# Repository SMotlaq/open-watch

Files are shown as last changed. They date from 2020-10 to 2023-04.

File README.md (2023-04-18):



<!-- PROJECT SHIELDS -->
[][contributors-url]
[][forks-url]
[][stars-url]
[][issues-url]
[][license-url]

<!-- TABLE OF CONTENTS -->
<details>
  <summary>Table of Contents</summary>
  <ol>
    <li><a href="#about-the-project">About The Project</a></li>
    <li><a href="#donation">Donation</a></li>
    <li><a href="#components">Components</a></li>
    <li><a href="#roadmap">Roadmap</a></li>
    <li><a href="#pictures">Pictures</a></li>
    <li><a href="#results">Results</a></li>
    <li><a href="#license">License</a></li>
    <li><a href="#refereces">Refereces</a></li>
    <li><a href="#contact">Contact</a></li>
  </ol>
</details>

<!-- ABOUT THE PROJECT -->
# About The Project

### Welcome to Open-Watch ✋🏻😃 a wearable device for health monitoring and fitness tracking.

**Special thanks to [PCBWay](https://www.pcbway.com/) for sponsoring us on this open-source project and providing [these](#pictures) awesome 4-layer PCBs!** Open-Watch is an open-source smartwatch project developed for our B.Sc. final thesis. This smartwatch can measure the linear acceleration of your hand, rotational speed, heart rate, and SpO2 (oxygen saturation). All of these data will be processed by an STM32 processor with an ARM Cortex-M core. You can find these essential components [here](#components).

MPU6050 was used for IMU purposes. We use the Kalman filter to reduce the noise effect and extract clean data from the sensor (3-axis linear acceleration, 3-axis rotational velocity, and 3-axis rotation angle).

MAX30102 is the sensor used for health care purposes. We just read raw data and devolve the processes to the smartphone.

Open-watch will send these collected data to a smartphone via a Bluetooth module. On the smartphone side, an Android app reads the data from Bluetooth and processes them. For health care applications like heart rate and SpO2 analysis, we use ML-based algorithms to extract these parameters from raw data read from the pulse-oximeter sensor. In this section a real-time algorithm for analysis of photoplethysmography signal (PPG) for measurement of SpO2 will be implemented.

The final valuable data will be shown on a smartphone as well as the smartwatch screen.

<div align="center">
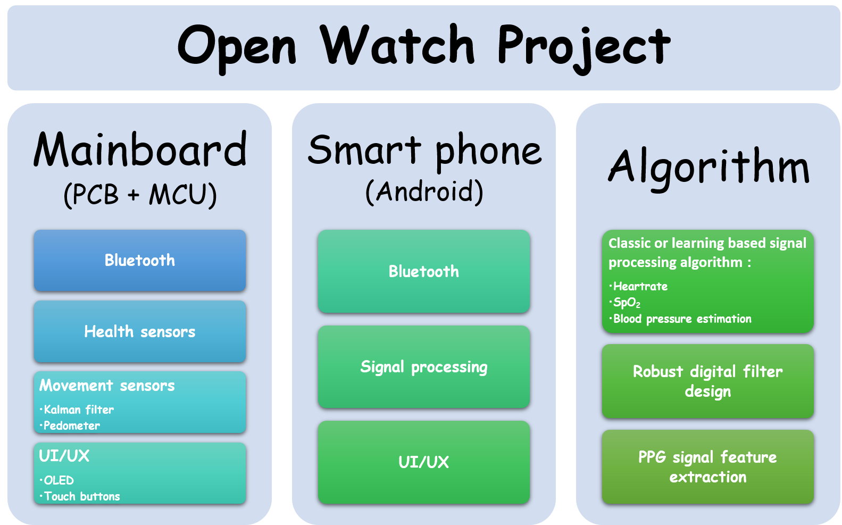
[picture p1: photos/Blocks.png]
    
</div>
<p align="right">(<a href="#top">back to top</a>)</p>

<!-- DONATION -->
# Donation

Do you want to support us in this project?

<p align="left">
  <a href="http://smotlaq.ir/LQgQF">
  Buy me a Coffee
  </a>
</p>

<p align="right">(<a href="#top">back to top</a>)</p>

# Components
 * 4-layer PCB: The PCBs of this project are provided by [PCBWay](https://www.pcbway.com), one of the best PCB factories in the world.
 * Main proccessor: [STM32F030C8 (ARM Cortex-M0)](https://www.javanelec.com/Shops/ProductDetail/24347)
 * Heartbeat and pulse oximeter sensor: [MAX30102](https://www.aliexpress.com/item/1005001863759524.html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)
 * Motion sensor: [MPU6050](http://skytech.ir/product_details.aspx?ID_Parts=2830&MPU6050)
 * Display: [1.3" OLED 64*128 pixels](http://skytech.ir/product_details.aspx?ID_Parts=2006&1.3-inch-I2C-OLED-SSD1306-Module)
 * Vibration [motor](https://www.javanelec.com/Shops/ProductDetail/38512)
 * Bluetooth: [HC-05](https://www.javanelec.com/Shops/ProductDetail/30407)
 * Touch driver: [BS814-A](https://micromodern.ir/shop/touch-key-ic/bs814a-1-msop10/)
 * Battery: [3.7v Li-Po](https://micmodshop.ir/eshop/battery-products/batteries/battery-lithium-polymer-3-7v-400mah-custom-00/)
 * Battery charger: [TP4056](http://skytech.ir/product_details.aspx?ID_Parts=9929&TP4056%20SOP8)

<p align="right">(<a href="#top">back to top</a>)</p>

<!-- ROADMAP -->
# Roadmap

- [x] Hardware design
  - [x] Microcontroller
  - [x] Vibration motor
  - [x] Bluetooth
  - [x] Buzzer
  - [x] Touch keys
  - [x] Charger
  - [X] PPG sensor
  - [X] MPU6050
- [X] PCB design
- [X] PCB Ordering
- [X] Body design
- [X] 3D print
- [x] Soldeing
- [x] Firmware programming
  - [x] RTC
  - [x] Alarm
  - [x] Bluetooth commands
  - [x] Vibration waves
  - [x] Buzzer
  - [x] OLED
    - [x] UI/UX
  - [x] Touch buttons
  - [x] Battery level indicator
  - [x] MPU6050
    - [x] Get raw data
    - [x] Kalman filter
    - [x] Movement detection
  - [x] PPG sensor
    - [x] Get raw data
    - [x] Transfer data using Bluetooth
- [x] Android programming
  - [x] Get blutooth data
  - [x] UI/UX
  - [x] Plot the raw PPG signals
  - [x] PPG data analysis
    - [x] Heartbeat
    - [x] SpO2
- [x] Assembling
- [x] Final test 😎

See the [open issues](https://github.com/SMotlaq/open-watch/issues) for a full list of proposed features (and known issues).

<p align="right">(<a href="#top">back to top</a>)</p>

<!-- PARTS -->
# Pictures

**OpenWatch**
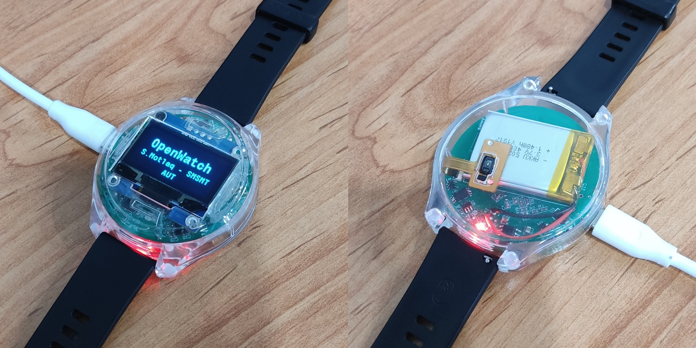
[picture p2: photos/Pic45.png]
 

<!-- ![full](photos/Pic45.png?raw=true "Fully assembled") -->

**PCB Overview**
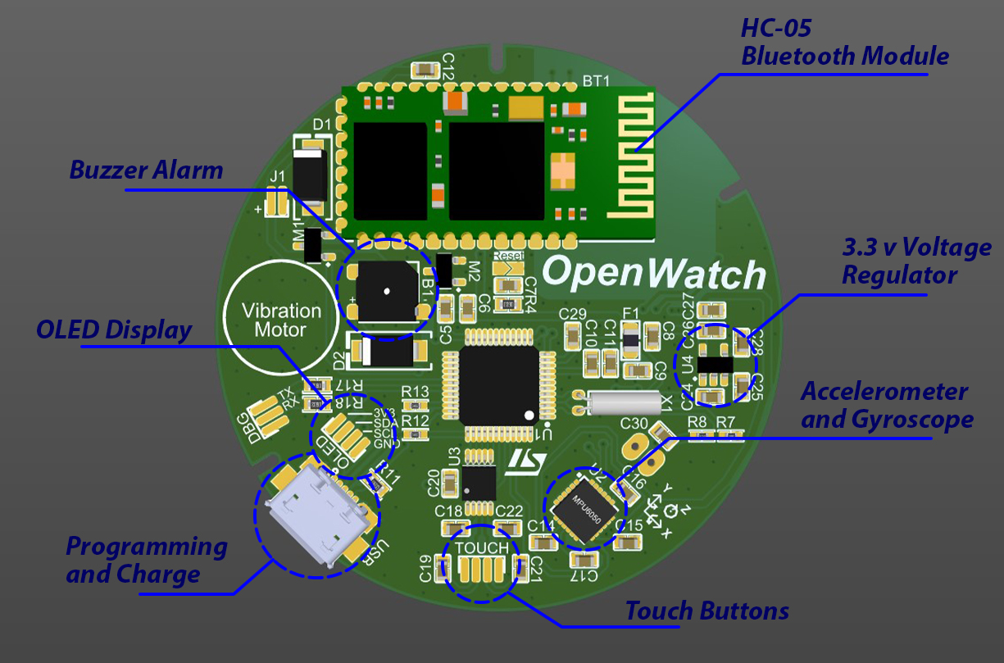
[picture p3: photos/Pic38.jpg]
 
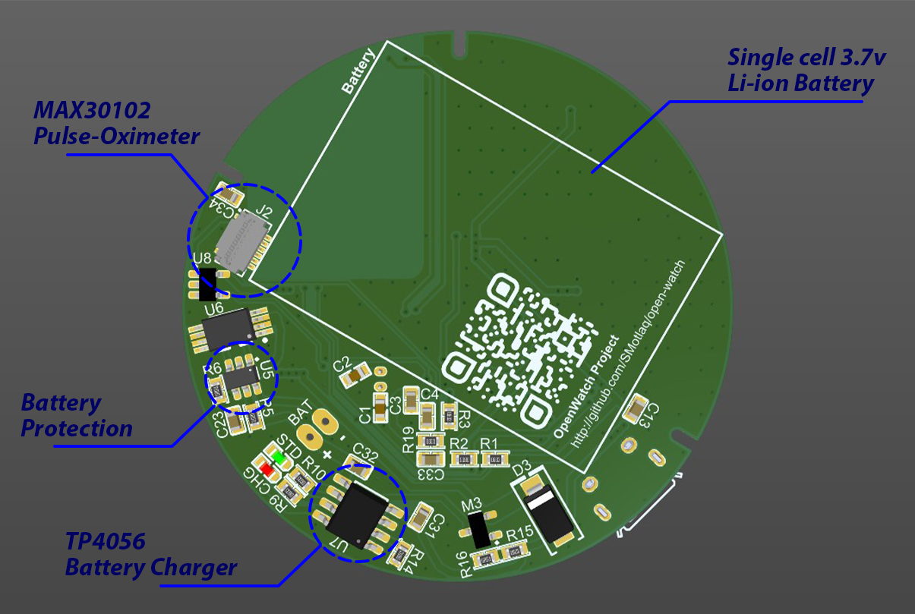
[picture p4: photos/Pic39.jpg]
 

<!-- ![overview-front](photos/Pic38.jpg?raw=true "Overview - Front")
![overview-back](photos/Pic39.jpg?raw=true "Overview - Back") -->

**PCB - 2D** 
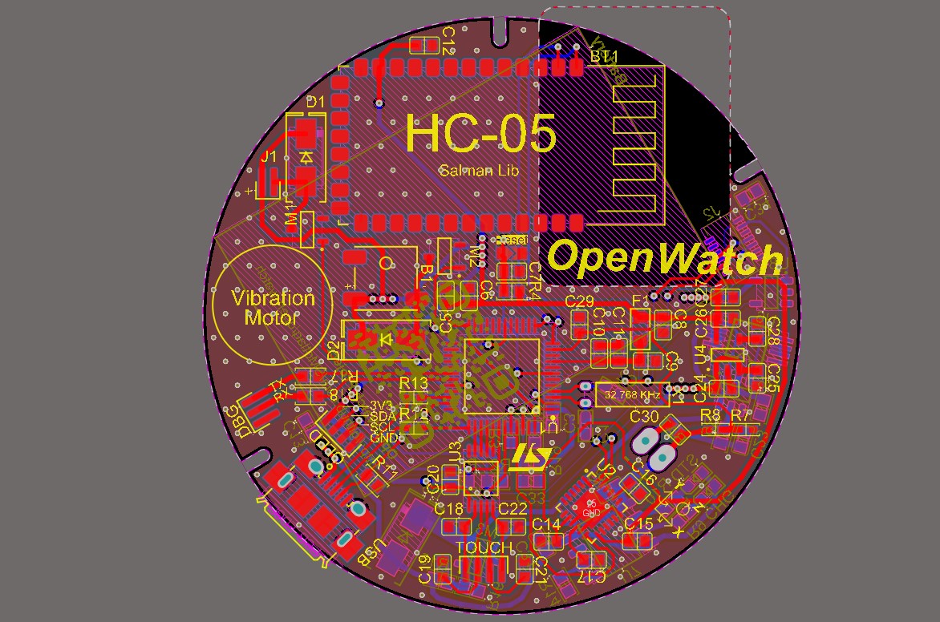
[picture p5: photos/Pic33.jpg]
 

<!-- ![2D](photos/Pic33.jpg?raw=true "2D view of main PCB - both layers") -->

**PCB - 3D** 
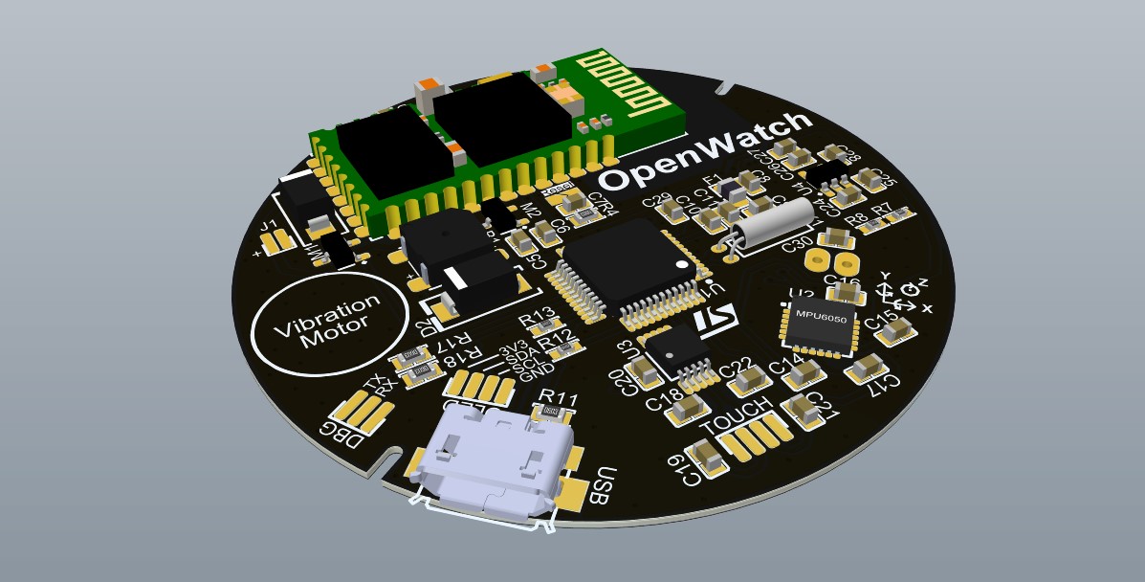
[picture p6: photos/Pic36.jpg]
  
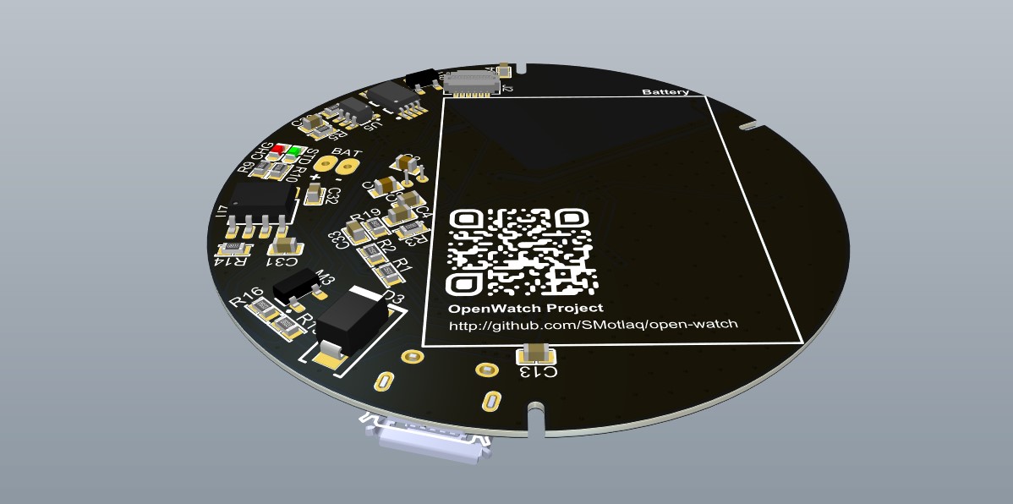
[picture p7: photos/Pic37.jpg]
 

<!-- ![3D-front](photos/Pic36.jpg?raw=true "3D view of main PCB - front")
![3D-back](photos/Pic37.jpg?raw=true "3D view of main PCB - back") -->

**PCB - Real**
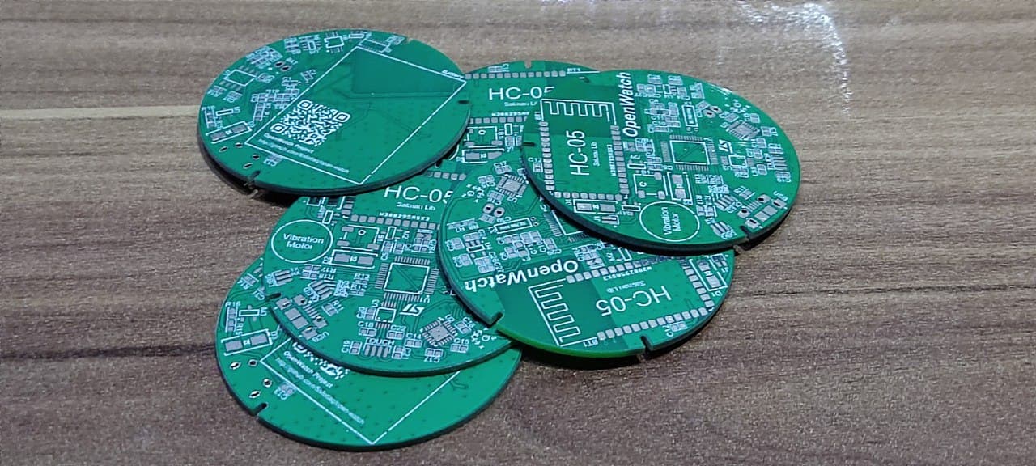
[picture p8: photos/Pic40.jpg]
  
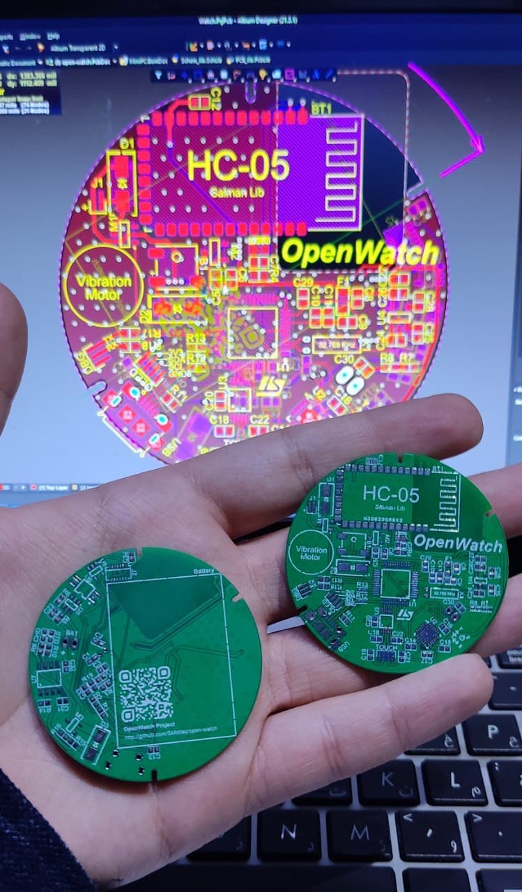
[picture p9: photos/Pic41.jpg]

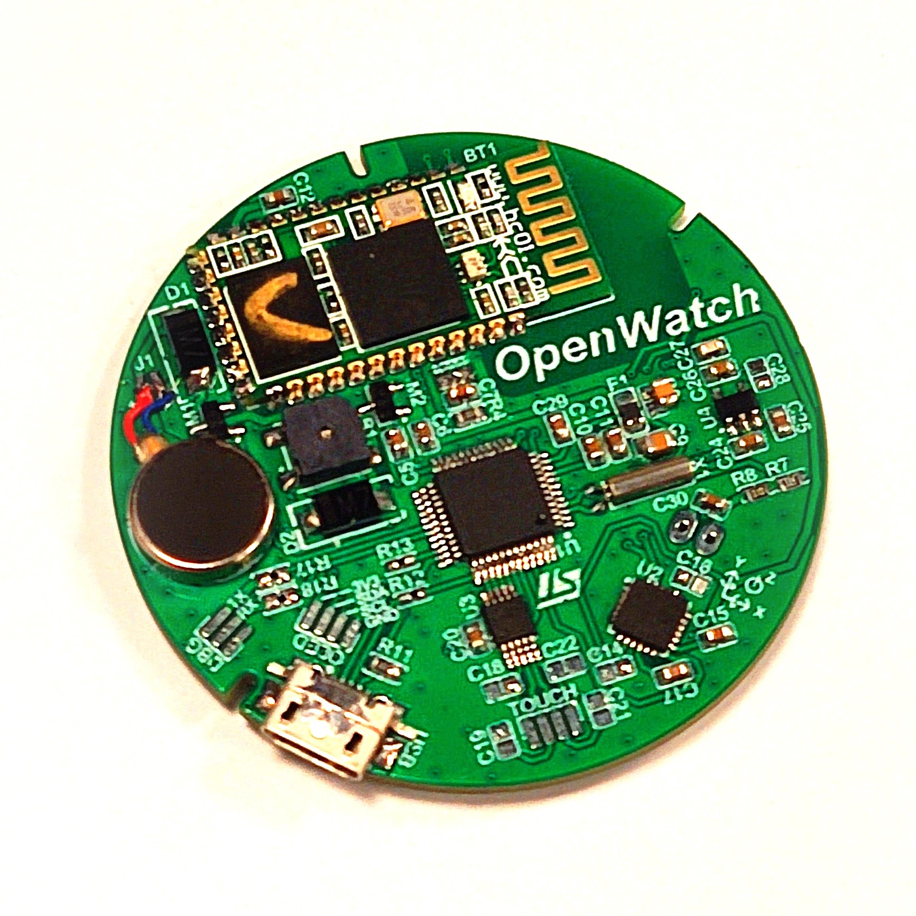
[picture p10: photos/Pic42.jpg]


<!-- ![real-front](photos/Pic32.jpg?raw=true "Real PCB view - front")
![real-back](photos/Pic31.jpg?raw=true "Real PCB view - back") -->

<p align="right">(<a href="#top">back to top</a>)</p>

<!-- STARS -->
# Star history

Star History Chart (https://star-history.com/#SMotlaq/open-watch&Date)

<p align="right">(<a href="#top">back to top</a>)</p>

<!-- LICENSE -->
# License

Distributed under the MIT License. See `LICENSE.txt` for more information.

<p align="right">(<a href="#top">back to top</a>)</p>

<!-- REFERENCES -->
# Refereces
**Dataset:**

MIMIC-III Database (https://mimic.mit.edu)

  [1] *Johnson, A., Pollard, T., & Mark, R. (2016). MIMIC-III Clinical Database (version 1.4). PhysioNet. https://doi.org/10.13026/C2XW26.*
  
  [2]	*Moody, B., Moody, G., Villarroel, M., Clifford, G., & Silva, I. (2020). MIMIC-III Waveform Database (version 1.0). PhysioNet. https://doi.org/10.13026/c2607m*
  
  [3]	*Kemp, J., Zhang, K., & Dai, A. (2020). MIMIC-III - SequenceExamples for TensorFlow modeling (version1.0.0). PhysioNet. https://doi.org/10.13026/n2v5-5b32.*
  
**Main references:**

 [1]	*Kiyasseh et al, CLOCS: Contrastive learning of cardiac signals across space, time, and patients, In Proc. ICML 2021*
 
 [2]	*Torres-Soto, J., Ashley, E.A. Multi-task deep learning for cardiac rhythm detection in wearable devices. npj Digit. Med. 3, 116 (2020). https://doi.org/10.1038/s41746-020-00320-4*
 
 [3]	*El Hajj C, Kyriacou P.A. Cuffless blood pressure estimation from PPG signals and its derivatives using deep learning models, Biomedical Signal Processing and Control. 70 (2021) https://doi.org/10.1016/j.bspc.2021.102984* 
 
 [4]	*Solà, J., & Delgado-Gonzalo, R. (2019). The Handbook of Cuffless Blood Pressure Monitoring: A Practical Guide for Clinicians, Researchers, and Engineers. The Handbook of Cuffless Blood Pressure Monitoring. https://doi.org/10.1007/978-3-030-24701-0*

<p align="right">(<a href="#top">back to top</a>)</p>

<!-- CONTACT -->
# Contact

Salman AmiMotlaq - [@SMotlaq](https://github.com/SMotlaq) - pilot.motlaq@gmail.com

Seyedmohammadsaleh Mirzatabatabaei - [@seyedsaleh](https://github.com/seyedsaleh) - seyedsaleh.edu@gmail.com

Amirhossein Aghajari - [@Aghajari](https://github.com/Aghajari) - amirhossein.aghajari.82@gmail.com

Project Link: [https://github.com/SMotlaq/open-watch](https://github.com/SMotlaq/open-watch)

<p align="right">(<a href="#top">back to top</a>)</p>

<!-- MARKDOWN LINKS & IMAGES -->
<!-- https://www.markdownguide.org/basic-syntax/#reference-style-links -->
[contributors-shield]: https://img.shields.io/github/contributors/SMotlaq/open-watch.svg?style=for-the-badge
[contributors-url]: https://github.com/SMotlaq/open-watch/graphs/contributors
[forks-shield]: https://img.shields.io/github/forks/SMotlaq/open-watch.svg?style=for-the-badge
[forks-url]: https://github.com/SMotlaq/open-watch/network/members
[stars-shield]: https://img.shields.io/github/stars/SMotlaq/open-watch.svg?style=for-the-badge
[stars-url]: https://github.com/SMotlaq/open-watch/stargazers
[issues-shield]: https://img.shields.io/github/issues/SMotlaq/open-watch.svg?style=for-the-badge
[issues-url]: https://github.com/SMotlaq/open-watch/issues
[license-shield]: https://img.shields.io/github/license/SMotlaq/open-watch.svg?style=for-the-badge
[license-url]: https://github.com/SMotlaq/open-watch/blob/master/LICENSE.txt

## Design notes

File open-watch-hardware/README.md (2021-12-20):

# Docs about open-watch hardware

## Things that should be changed in future versions:
 * Connect 8th pin of TP4056 to MCU. It will let us to control battery charging.
 * Swap the Rx & Tx of Bluetooth
 * Connect PIO11 (HC-05) to MCU for changing the name, password, baudrate, etc.
 * Connect USB_DETECT label to +5V of USB instead of ID pin.

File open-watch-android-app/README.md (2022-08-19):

# open-watch android app

**Libraries/Projects Used:**
- [XmlByPass](https://github.com/Aghajari/XmlByPass)
- [AXAnimation](https://github.com/Aghajari/AXAnimation)
- [AXGraphView](https://github.com/Aghajari/AXGraphView)
- [AXPathLoadingView](https://github.com/Aghajari/AXPathLoadingView)
- [SimpleChart](https://github.com/Aghajari/SimpleChart)

## Connection
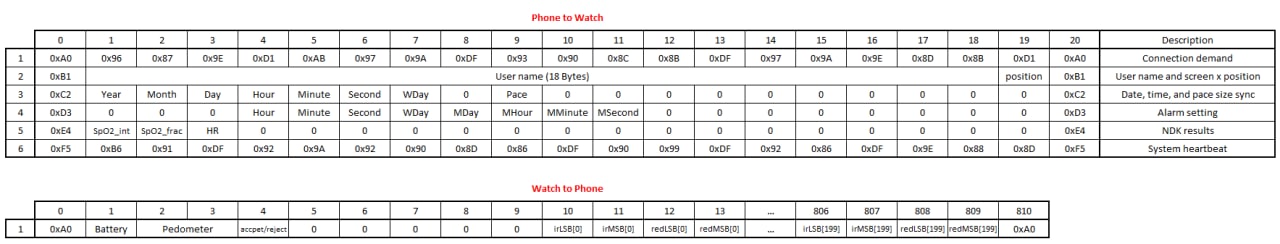
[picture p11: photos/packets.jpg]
Packets


Android app connects to watch via classic bluetooth. <br>
Whenever the socket created, android app sends the `Connection demand` packet and waits for the acknowledge.<br>
Then app sends a filtered username to the watch so watch can say Hello to that user.<br>
At the end app sends some config data to the watch such as user's device date & time and user's step-size to calculate distance in km.<br>
App sends the `System heartbeat` packet to watch every 800ms so that watch verifies the app.<br>
App sends the `Alarm setting` packet whenever the user sets an alarm.<br>
Whenever the watch sends 5 signal packets (1000 samples) to the app, the PPG algorithms will filter the signal and calculate HR and SpO2, and then the app will send the `NDK results` packet to the watch.

## Graph

[AXGraphView](https://github.com/Aghajari/AXGraphView) is customized so that it can increase the range of the time (x) domain by zooming and it is possible to move only in the time axis. Also, scrolling will start automatically upon receiving signals from the watch. The coordinate axis has been moved to (0, 0) and the library is ready to display two different graphs (Red and iRed) in one view.

## HRV Chart

[SimpleChart](https://github.com/Aghajari/SimpleChart)'s LineChart is customized to match the graph's grid-lines design and the gradient animation. Also, the y range is calculated more accurately and a linear animation has been added to display the chart.

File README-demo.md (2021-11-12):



<!-- PROJECT SHIELDS -->
[][contributors-url]
[][forks-url]
[][stars-url]
[][issues-url]
[][license-url]

<!-- PROJECT LOGO -->
<br />
<div align="center">

  <h3 align="center">open-watch</h3>

  <p align="center">
    Smart Wearable Health Monitoring and Fitness Tracking Device
    <br />
    <a href="https://github.com/SMotlaq/open-watch"><strong>Explore the docs »</strong></a>
    <br />
    <br />
    <a href="https://github.com/SMotlaq/open-watch/issues">Report Bug & Request Feature</a>
  </p>
</div>

<!-- TABLE OF CONTENTS -->
<details>
  <summary>Table of Contents</summary>
  <ol>
    <li>
      <a href="#about-the-project">About The Project</a>
      <ul>
        <li><a href="#components">Components</a></li>
      </ul>
    </li>
    <li><a href="#roadmap">Roadmap</a></li>
    <li><a href="#parts">Parts</a></li>
    <li><a href="#results">Results</a></li>
    <li><a href="#license">License</a></li>
    <li><a href="#refereces">Refereces</a></li>
    <li><a href="#contact">Contact</a></li>
    <li><a href="#donation">Donation</a></li>
  </ol>
</details>

<!-- ABOUT THE PROJECT -->
## About The Project

Welcome to Open-Watch ✋🏻😃

Open-Watch is an open source project developed for our BSc final thesis. Wait to hear more from us!
<div align="center">
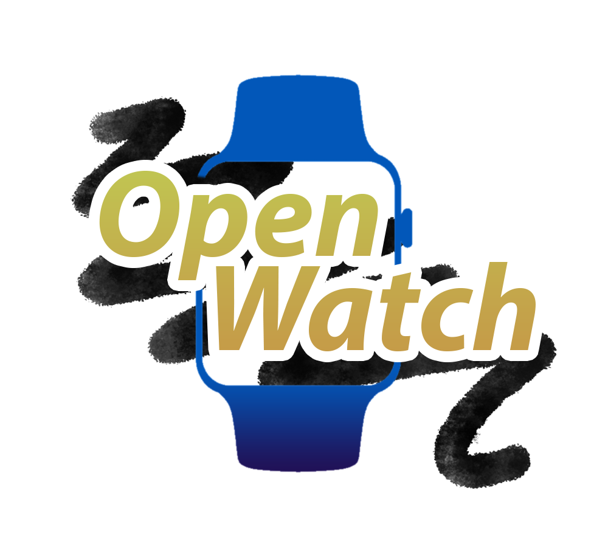
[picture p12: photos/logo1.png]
    
</div>
<p align="right">(<a href="#top">back to top</a>)</p>

### Components
 * Main proccessor: [STM32F030C8 (ARM core)](https://www.javanelec.com/Shops/ProductDetail/24347)
 * Heartbeat and pulse oximeter sensor: [MAX30102](https://www.aliexpress.com/item/1005001863759524.html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)
 * Motion sensor: [MPU6050](http://skytech.ir/product_details.aspx?ID_Parts=2830&MPU6050)
 * Display: [1.3" OLED 64*128 pixels](http://skytech.ir/product_details.aspx?ID_Parts=2006&1.3-inch-I2C-OLED-SSD1306-Module)
 * Vibration [motor](https://www.javanelec.com/Shops/ProductDetail/38512)
 * Bluetooth: [HC-05](https://www.javanelec.com/Shops/ProductDetail/30407)
 * Touch driver: [BS814-A](https://micromodern.ir/shop/touch-key-ic/bs814a-1-msop10/)
 * Battery: [3.7v Li-Po](https://micmodshop.ir/eshop/battery-products/batteries/battery-lithium-polymer-3-7v-400mah-custom-00/)
 * Battery charger: [TP4056](http://skytech.ir/product_details.aspx?ID_Parts=9929&TP4056%20SOP8)

<p align="right">(<a href="#top">back to top</a>)</p>

<!-- ROADMAP -->
## Roadmap

- [x] Hardware design
  - [x] Microcontroller
  - [x] Vibration motor
  - [x] Bluetooth
  - [x] Buzzer
  - [x] Touch keys
  - [x] Charger
  - [X] PPG sensor
  - [X] MPU6050
- [X] PCB design
- [X] PCB Ordering
- [ ] Body design
- [ ] 3D print
- [ ] Soldeing
- [ ] Firmware programming
  - [ ] RTC
  - [ ] Bluetooth commands
  - [ ] Vibration waves
  - [ ] OLED
  - [ ] Touch buttons
  - [ ] Battery level indicator
  - [ ] Power saving
  - [ ] MPU6050
  - [ ] PPG sensor
- [ ] Android programming
- [ ] Assembling
- [ ] Final test 😎

See the [open issues](https://github.com/SMotlaq/open-watch/issues) for a full list of proposed features (and known issues).

<p align="right">(<a href="#top">back to top</a>)</p>

<!-- PARTS -->
## Parts

**Overview**
 
 

<!-- ![overview-front](photos/Pic38.jpg?raw=true "Overview - Front")
![overview-back](photos/Pic39.jpg?raw=true "Overview - Back") -->

**PCB - 2D** 
 

<!-- ![2D](photos/Pic33.jpg?raw=true "2D view of main PCB - both layers") -->

**PCB - 3D** 
  
 

<!-- ![3D-front](photos/Pic36.jpg?raw=true "3D view of main PCB - front")
![3D-back](photos/Pic37.jpg?raw=true "3D view of main PCB - back") -->

**PCB - Real** (***These pictures belong to the previous version***) 
  
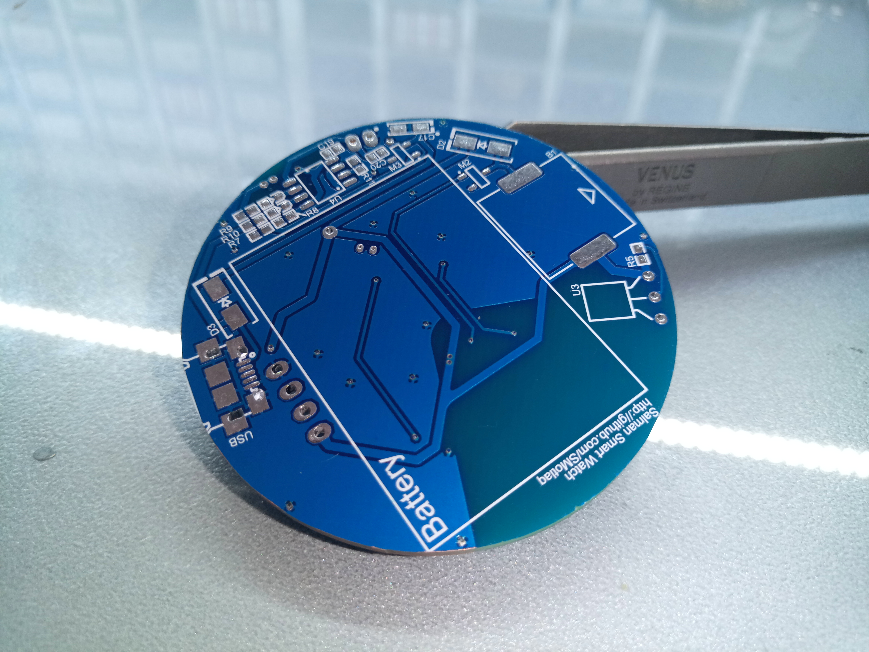
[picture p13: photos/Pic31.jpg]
 

<!-- ![real-front](photos/Pic32.jpg?raw=true "Real PCB view - front")
![real-back](photos/Pic31.jpg?raw=true "Real PCB view - back") -->

<p align="right">(<a href="#top">back to top</a>)</p>

<!-- RESULTS -->
## Results

<p align="right">(<a href="#top">back to top</a>)</p>

<!-- LICENSE -->
## License

Distributed under the MIT License. See `LICENSE.txt` for more information.

<p align="right">(<a href="#top">back to top</a>)</p>

<!-- REFERENCES -->
## Refereces

[1] *blablabla* 

<p align="right">(<a href="#top">back to top</a>)</p>

<!-- CONTACT -->
## Contact

Salman AmiMotlaq - [@SMotlaq](https://github.com/SMotlaq) - pilot.motlaq@gmail.com

Seyedmohammadsaleh Mirzatabatabaei - [@seyedsaleh](https://github.com/seyedsaleh) - seyedsaleh.edu@gmail.com

Project Link: [https://github.com/SMotlaq/open-watch](https://github.com/SMotlaq/open-watch)

<p align="right">(<a href="#top">back to top</a>)</p>

<!-- DONATION -->
## Donation

Do you want to suuport us in this project?

<p align="left">
  <a href="http://smotlaq.ir/LQgQF">
  Buy me a Coffee
  </a>
</p>

<p align="right">(<a href="#top">back to top</a>)</p>

---
<div align="center">
<p>
 
 
</p>
</div>

<!-- MARKDOWN LINKS & IMAGES -->
<!-- https://www.markdownguide.org/basic-syntax/#reference-style-links -->
[contributors-shield]: https://img.shields.io/github/contributors/SMotlaq/open-watch.svg?style=for-the-badge
[contributors-url]: https://github.com/SMotlaq/open-watch/graphs/contributors
[forks-shield]: https://img.shields.io/github/forks/SMotlaq/open-watch.svg?style=for-the-badge
[forks-url]: https://github.com/SMotlaq/open-watch/network/members
[stars-shield]: https://img.shields.io/github/stars/SMotlaq/open-watch.svg?style=for-the-badge
[stars-url]: https://github.com/SMotlaq/open-watch/stargazers
[issues-shield]: https://img.shields.io/github/issues/SMotlaq/open-watch.svg?style=for-the-badge
[issues-url]: https://github.com/SMotlaq/open-watch/issues
[license-shield]: https://img.shields.io/github/license/SMotlaq/open-watch.svg?style=for-the-badge
[license-url]: https://github.com/SMotlaq/open-watch/blob/master/LICENSE.txt

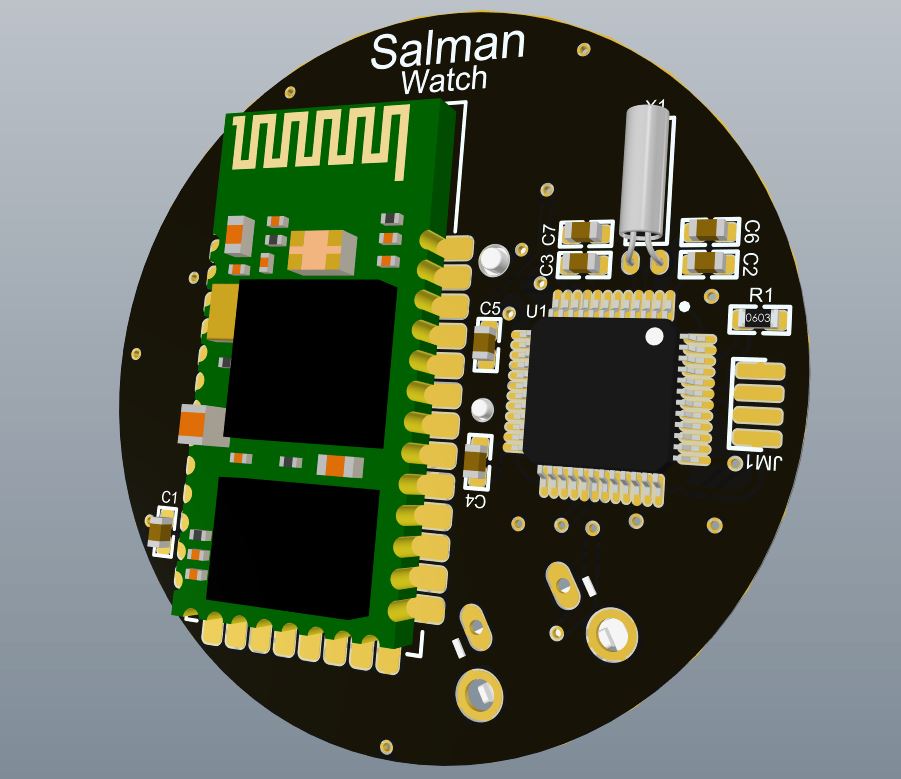
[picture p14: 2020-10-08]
photos/Pic1.JPG

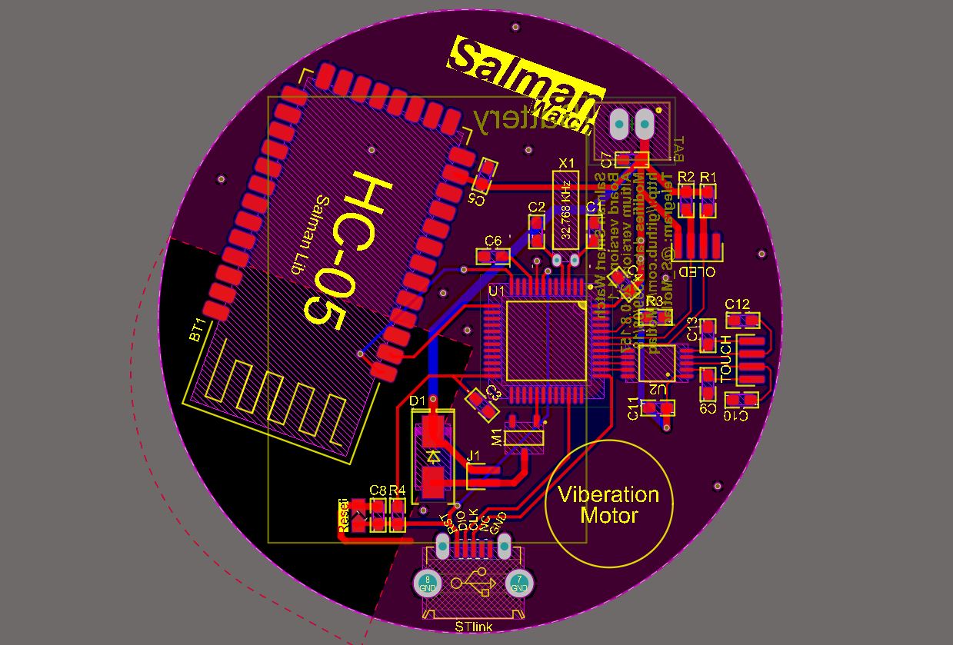
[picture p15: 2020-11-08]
photos/Pic8.JPG

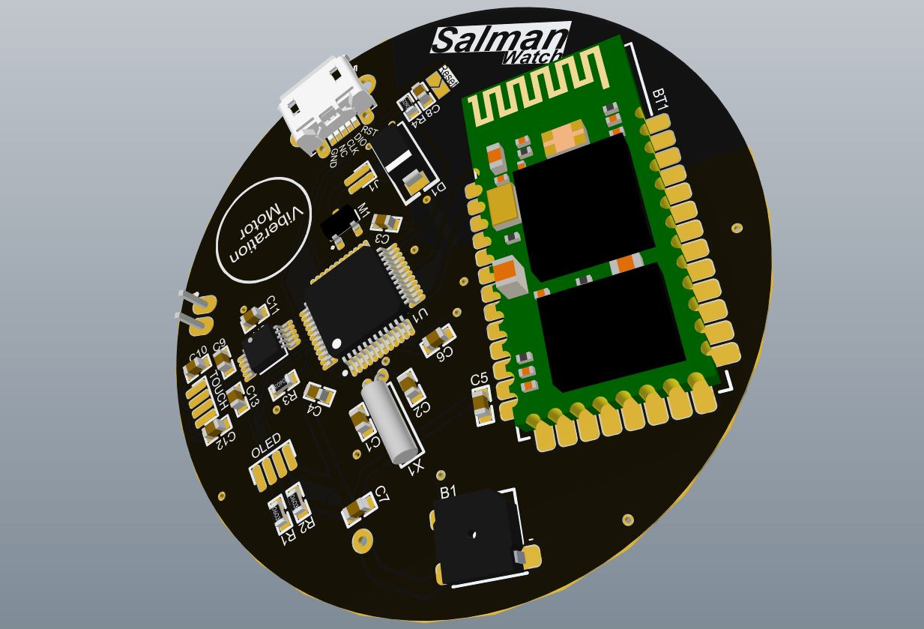
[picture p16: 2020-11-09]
photos/Pic14.JPG

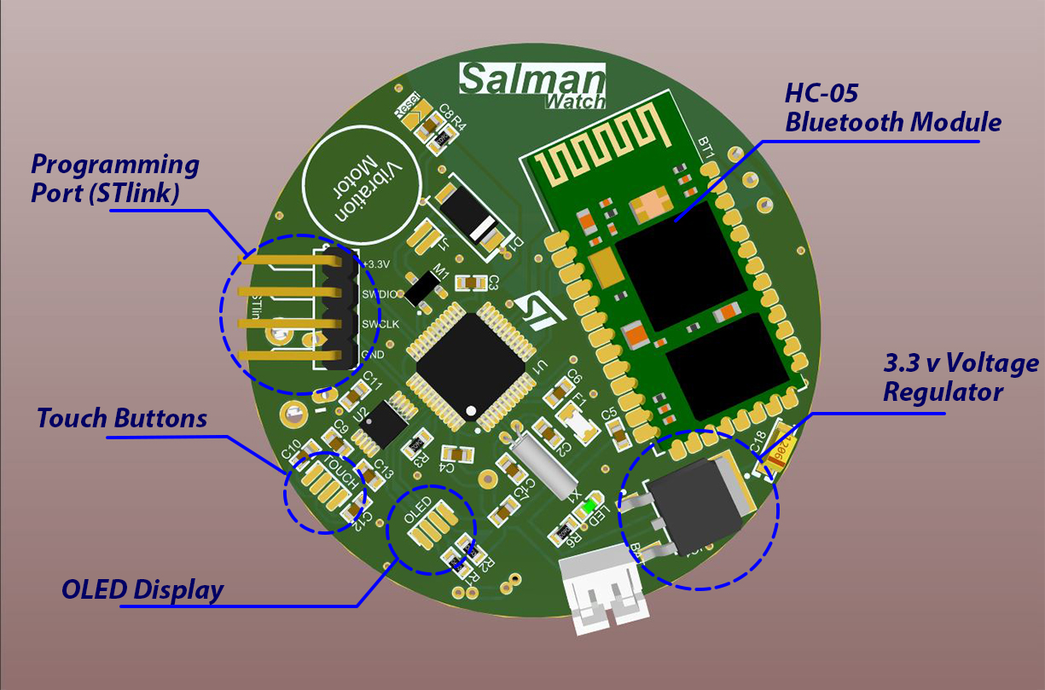
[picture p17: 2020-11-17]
photos/Pic29.jpg

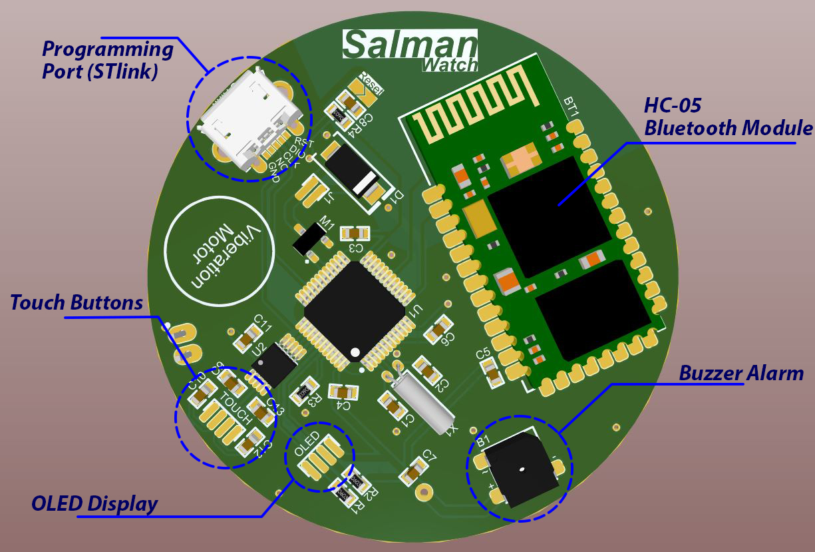
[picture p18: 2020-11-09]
photos/Pic16.jpg

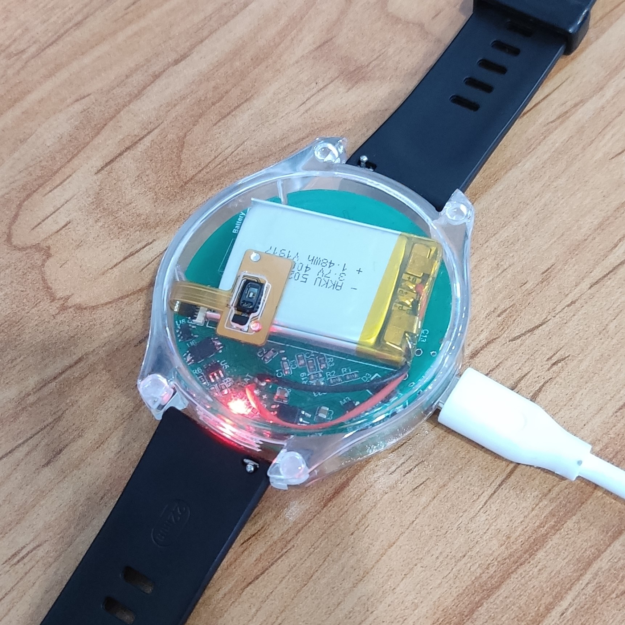
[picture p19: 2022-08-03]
photos/Pic44.jpg

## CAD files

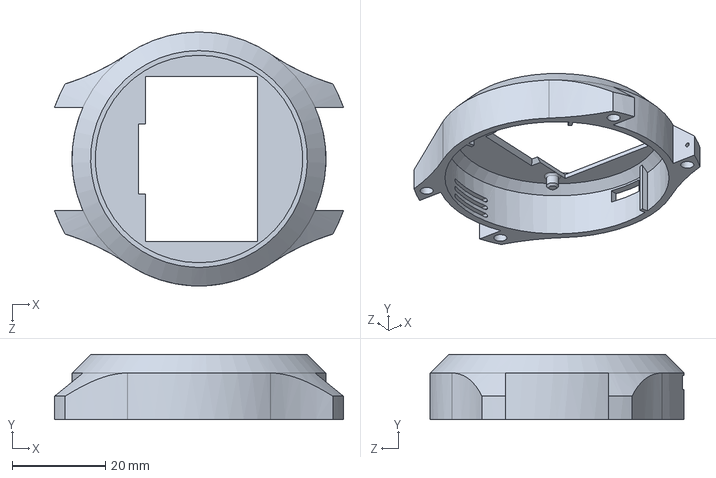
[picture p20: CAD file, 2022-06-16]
open-watch-mechanical/main.SLDPRT
62.0 x 14.0 x 54.5 mm

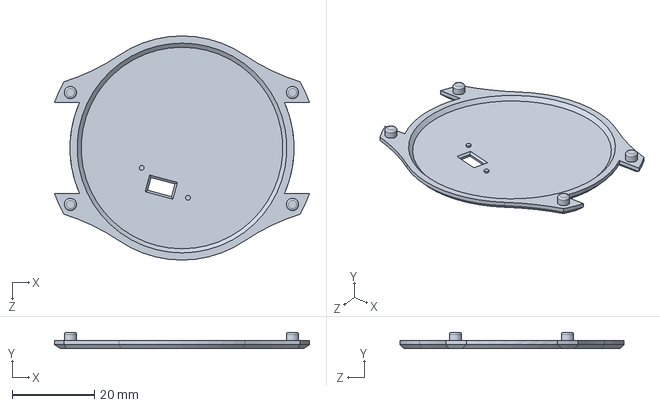
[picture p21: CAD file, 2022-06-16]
open-watch-mechanical/back.SLDPRT
62.0 x 4.00 x 54.5 mm

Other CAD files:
open-watch-mechanical/back.STL
open-watch-mechanical/main.STL

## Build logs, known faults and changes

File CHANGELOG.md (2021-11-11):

# Changelog

## v1.0.0

### Added or Changed
- Added this changelog :)

### Removed

-

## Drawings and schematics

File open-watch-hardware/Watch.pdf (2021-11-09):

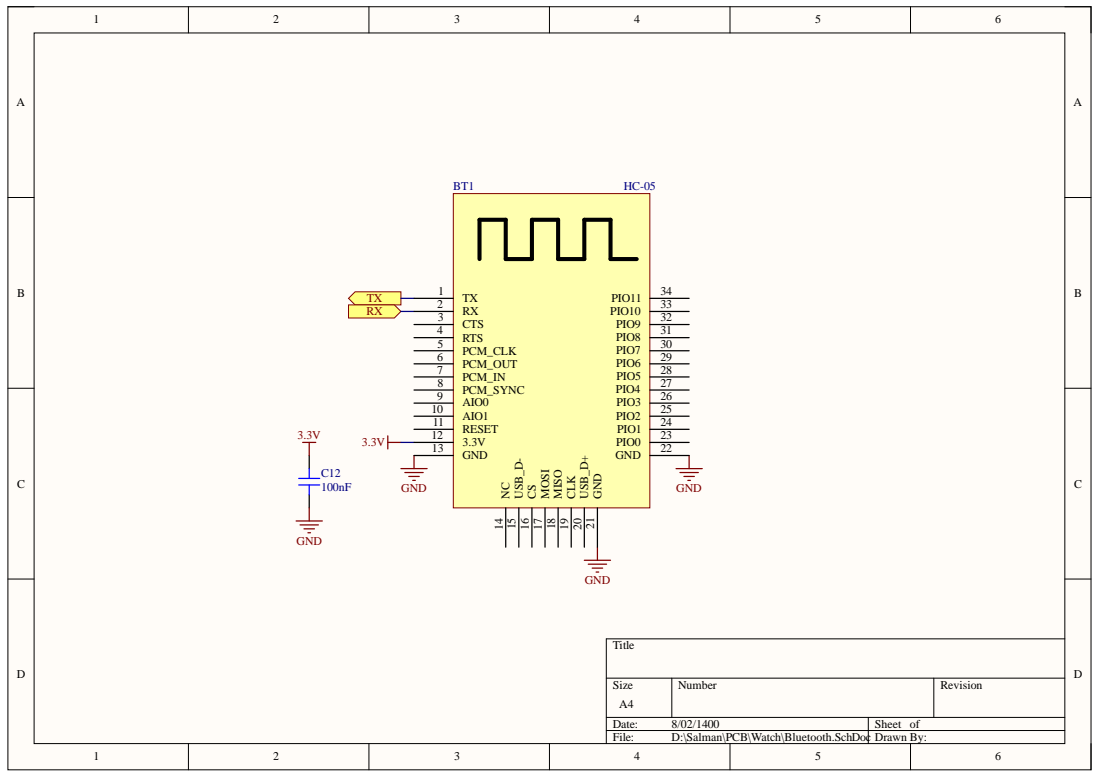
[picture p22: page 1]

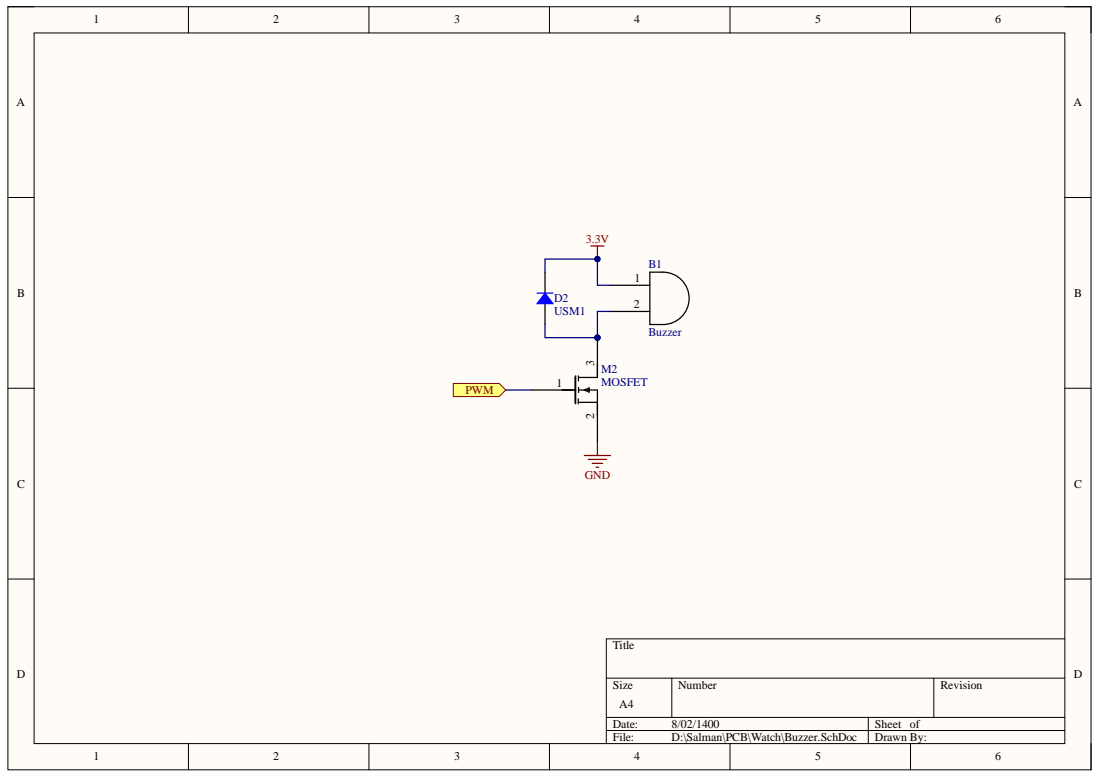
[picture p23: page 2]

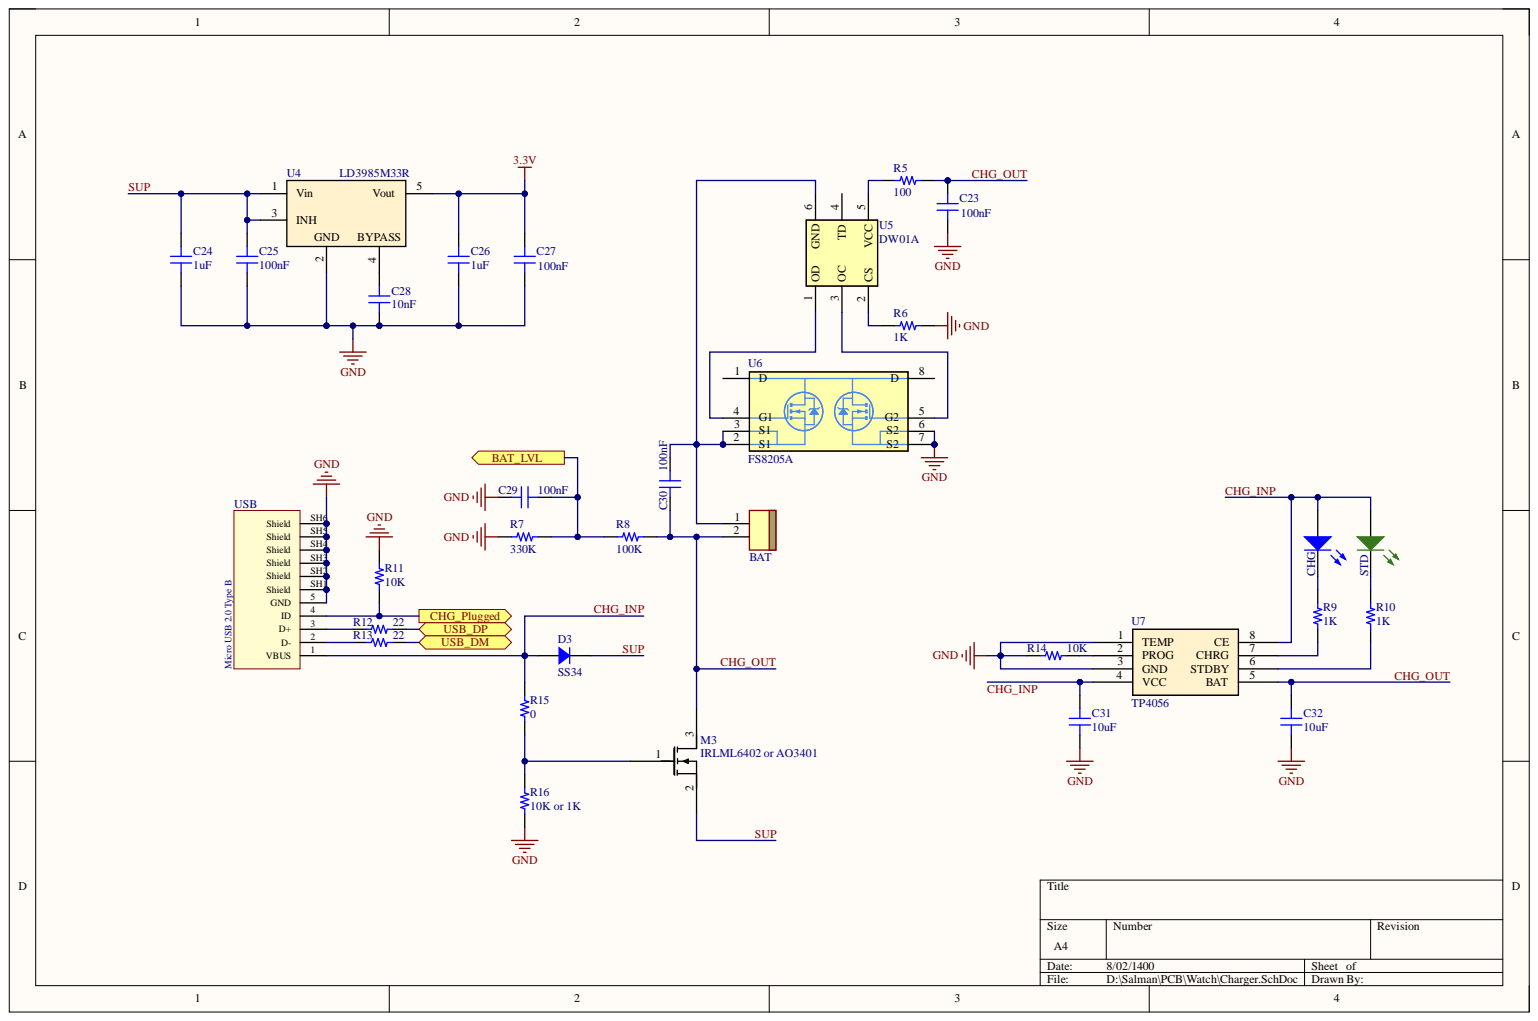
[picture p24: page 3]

R1 4 1 0 K | 2 | | 5 STDBY 6 CHRG 7 CE 8

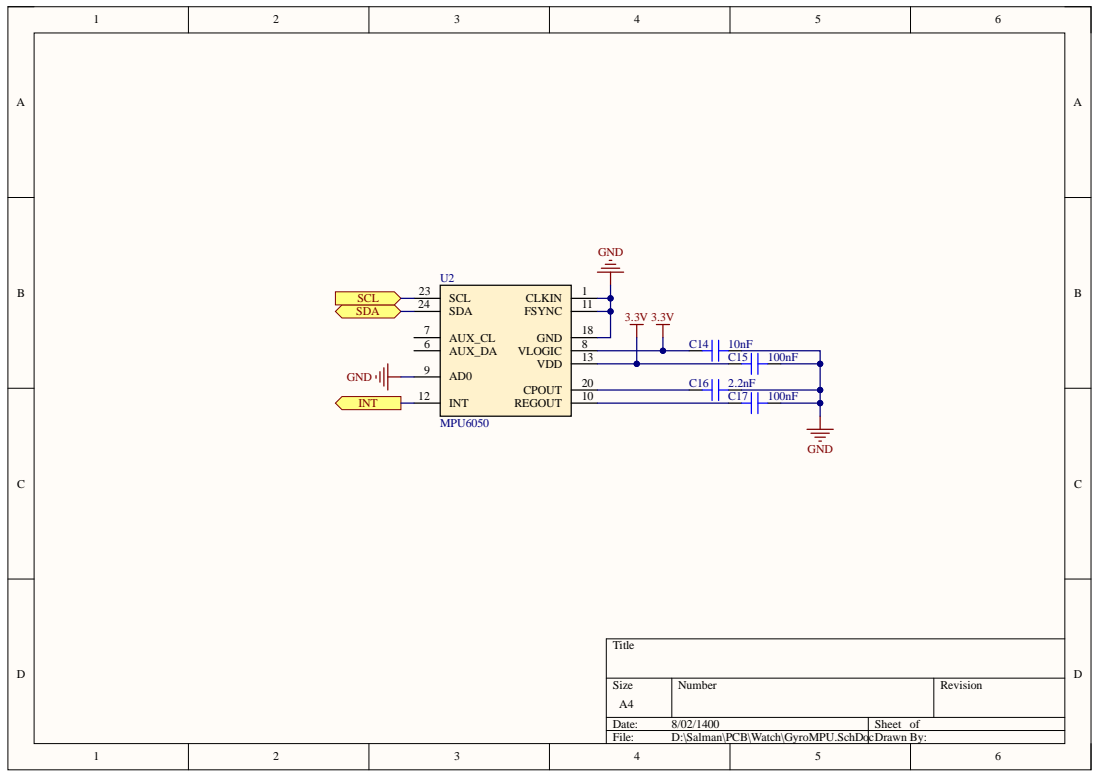
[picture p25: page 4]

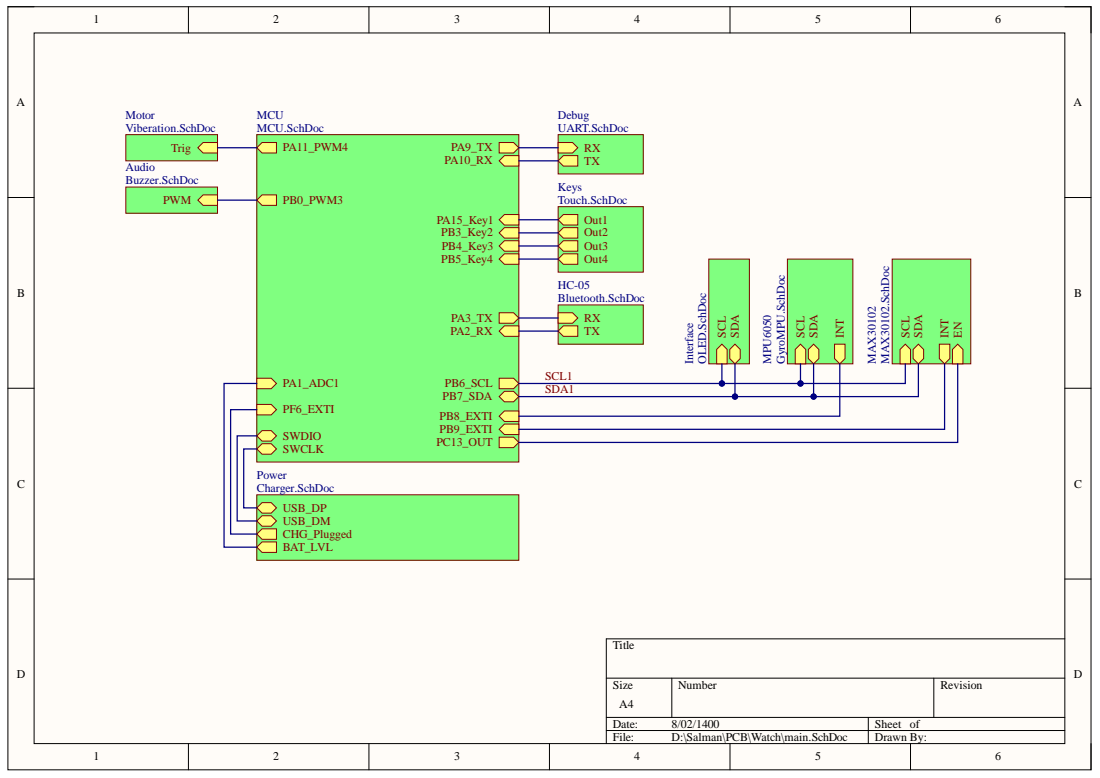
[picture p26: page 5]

SCL1
SDA1

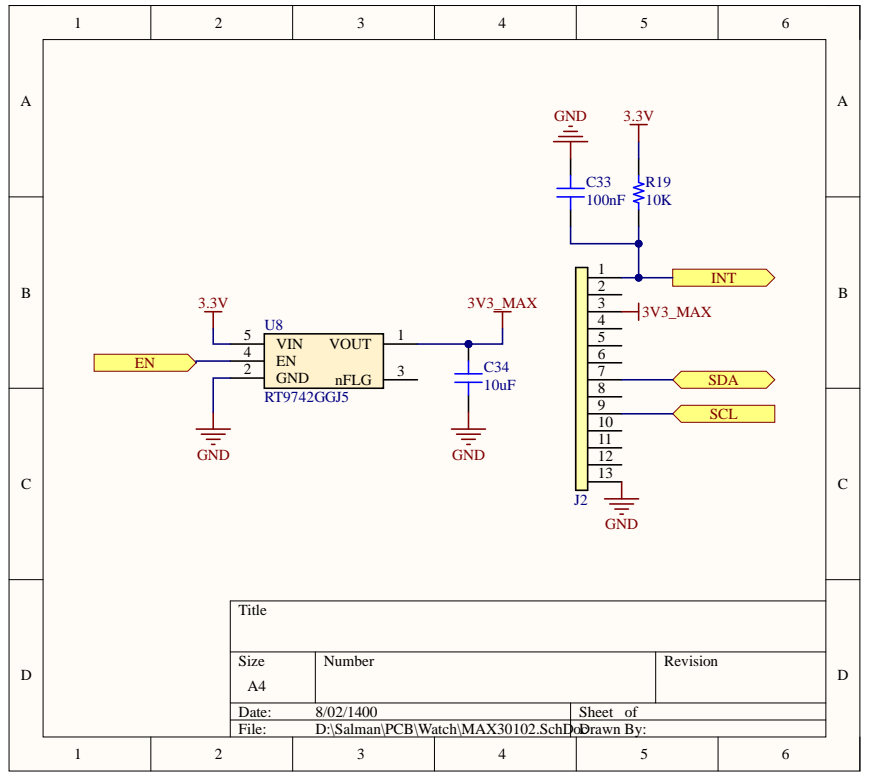
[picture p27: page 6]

Size A4 | Number | Revision

Date: 8/02/1400 | Sheet of
File: D:\Salman\PCB\Watch\MAX30102.SchDoDrawn c | By:

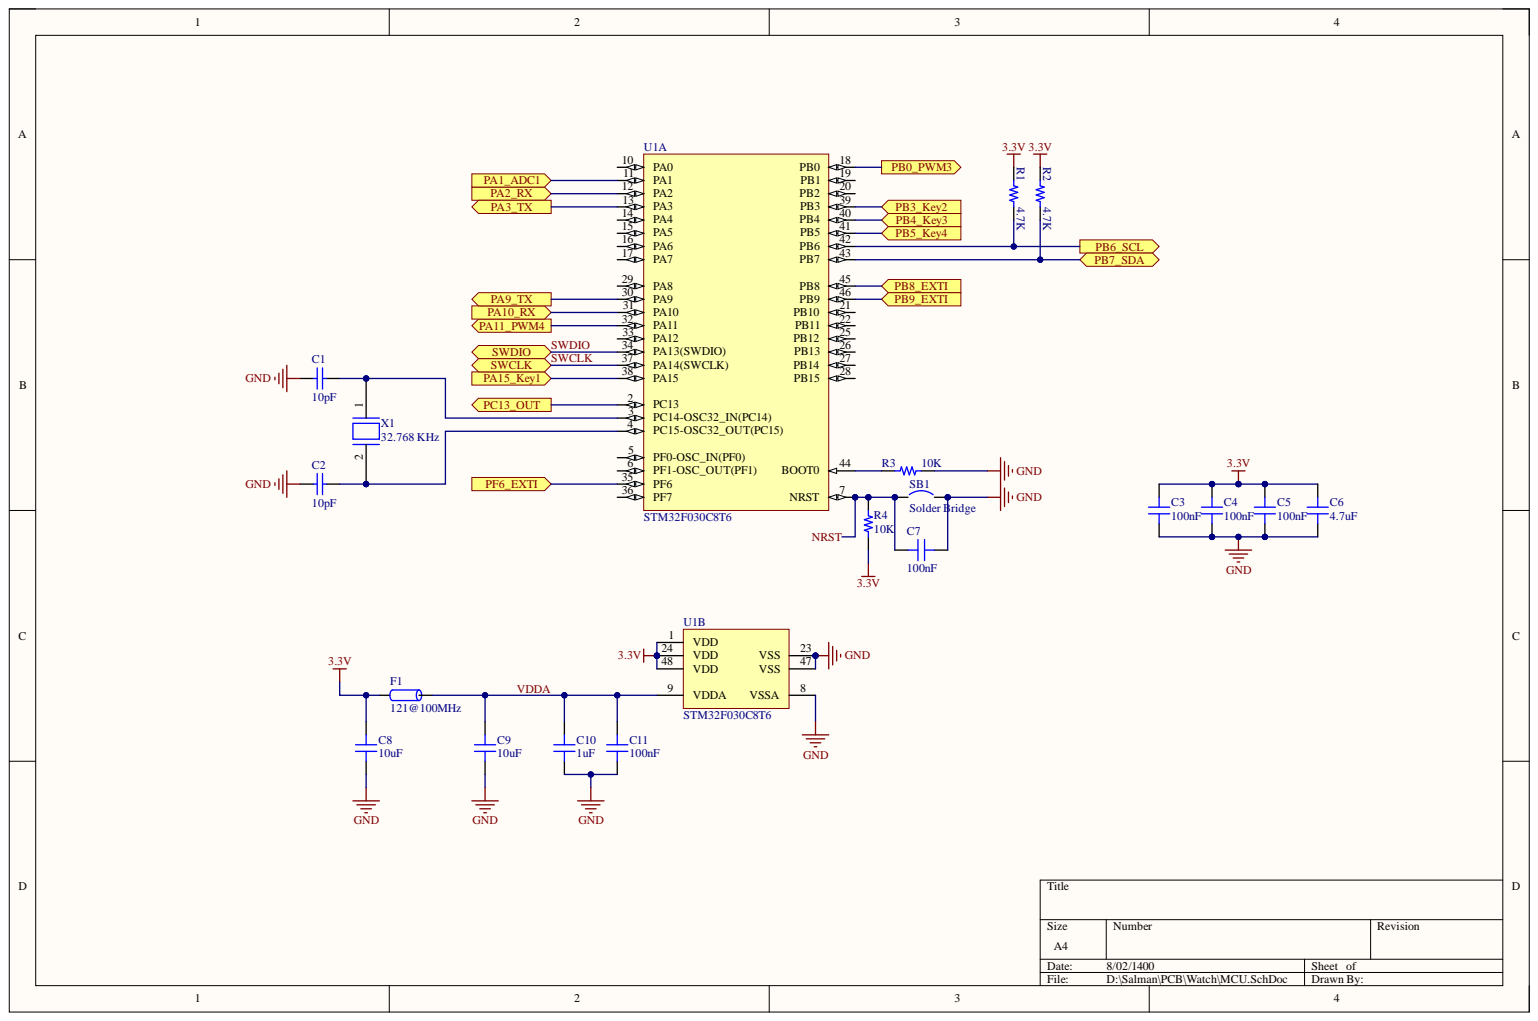
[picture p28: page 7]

PC13_OUT | | PC13 2 PC14-OSC32_IN(PC14) 3

X1 | PC15-OSC32_OUT(PC15) 4

PF0-OSC_IN(PF0) 5

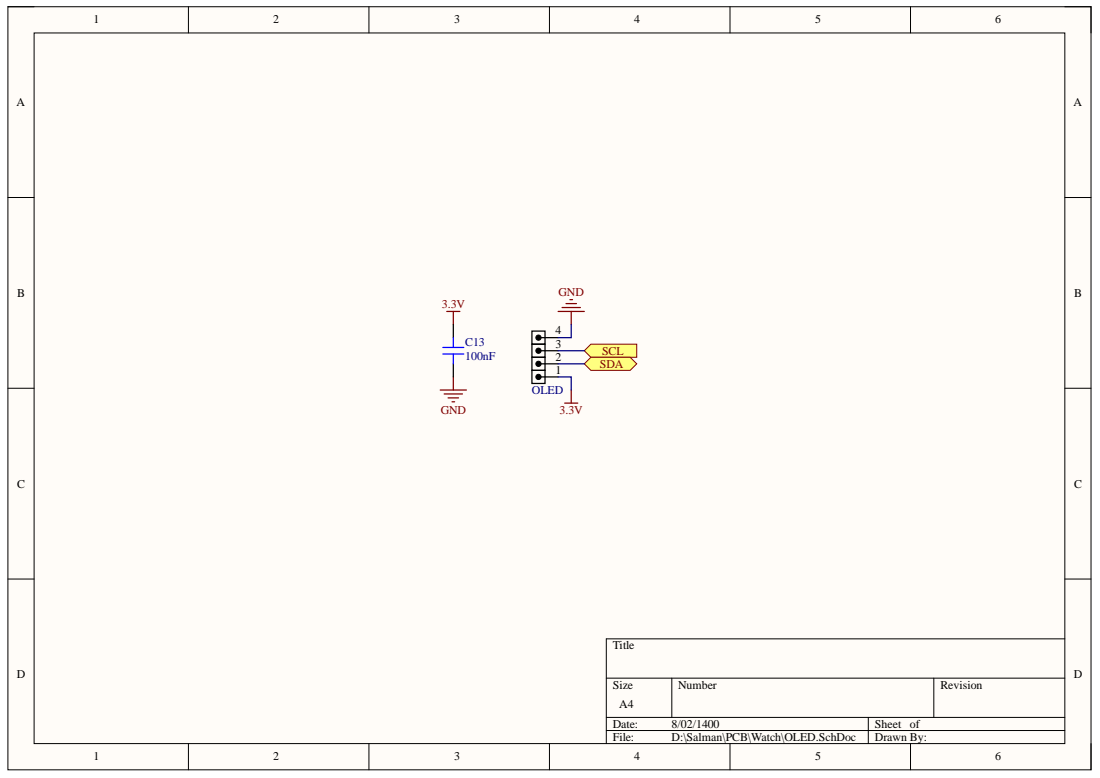
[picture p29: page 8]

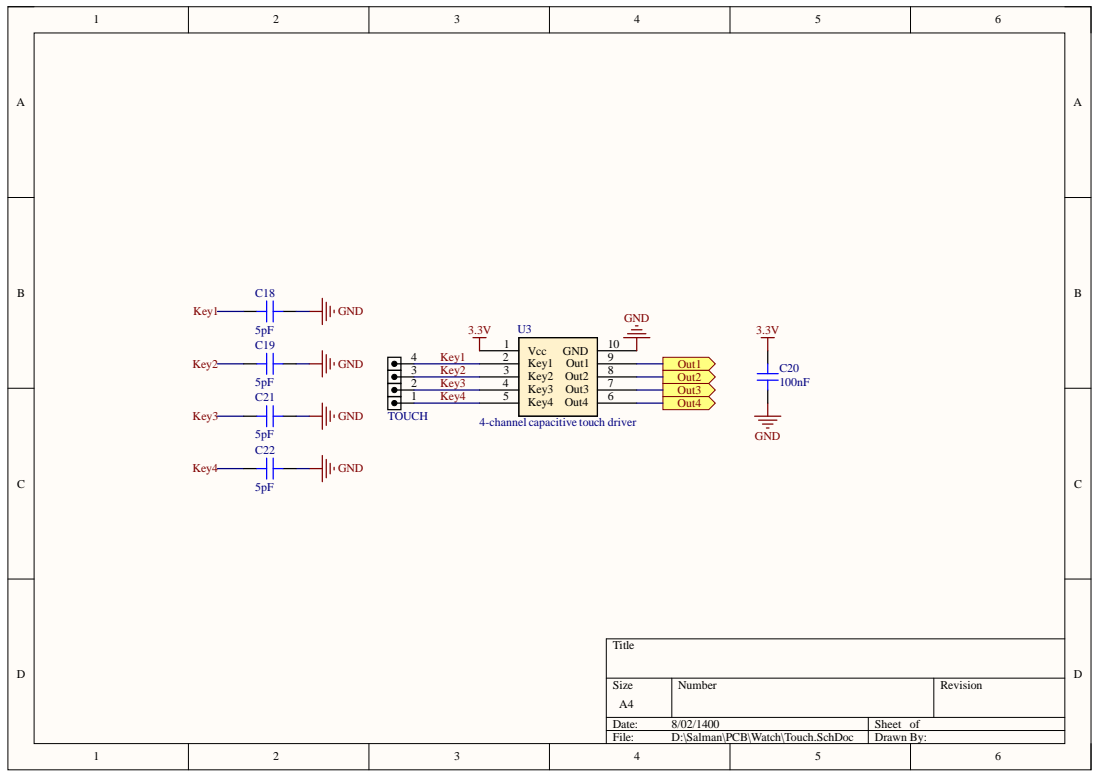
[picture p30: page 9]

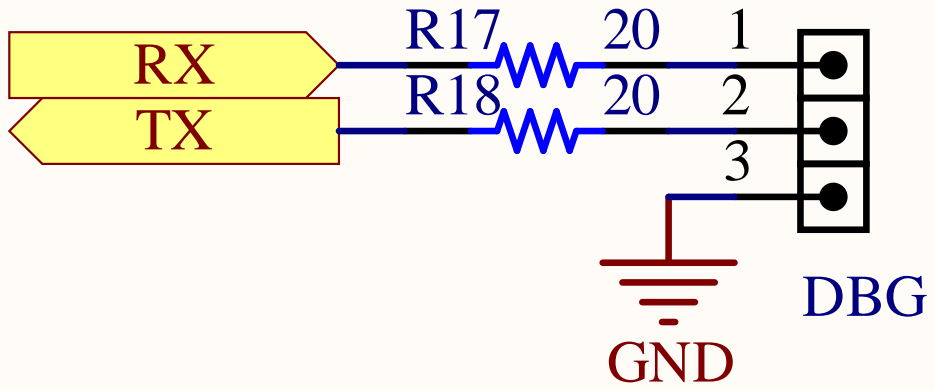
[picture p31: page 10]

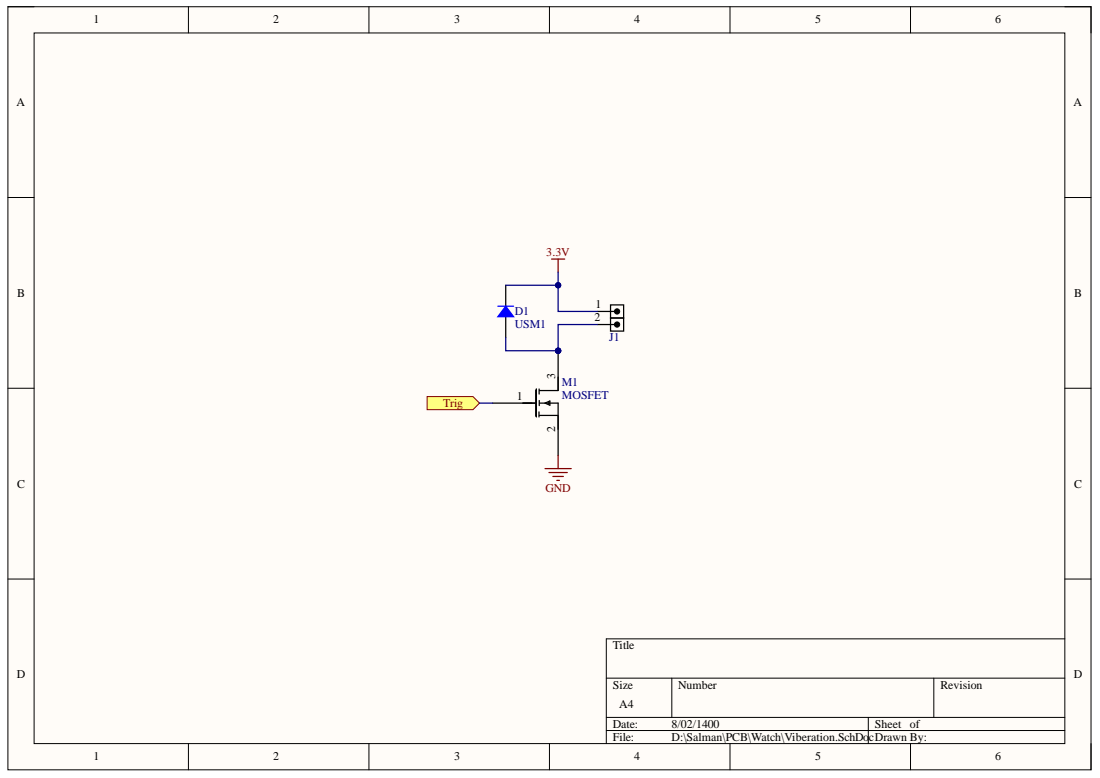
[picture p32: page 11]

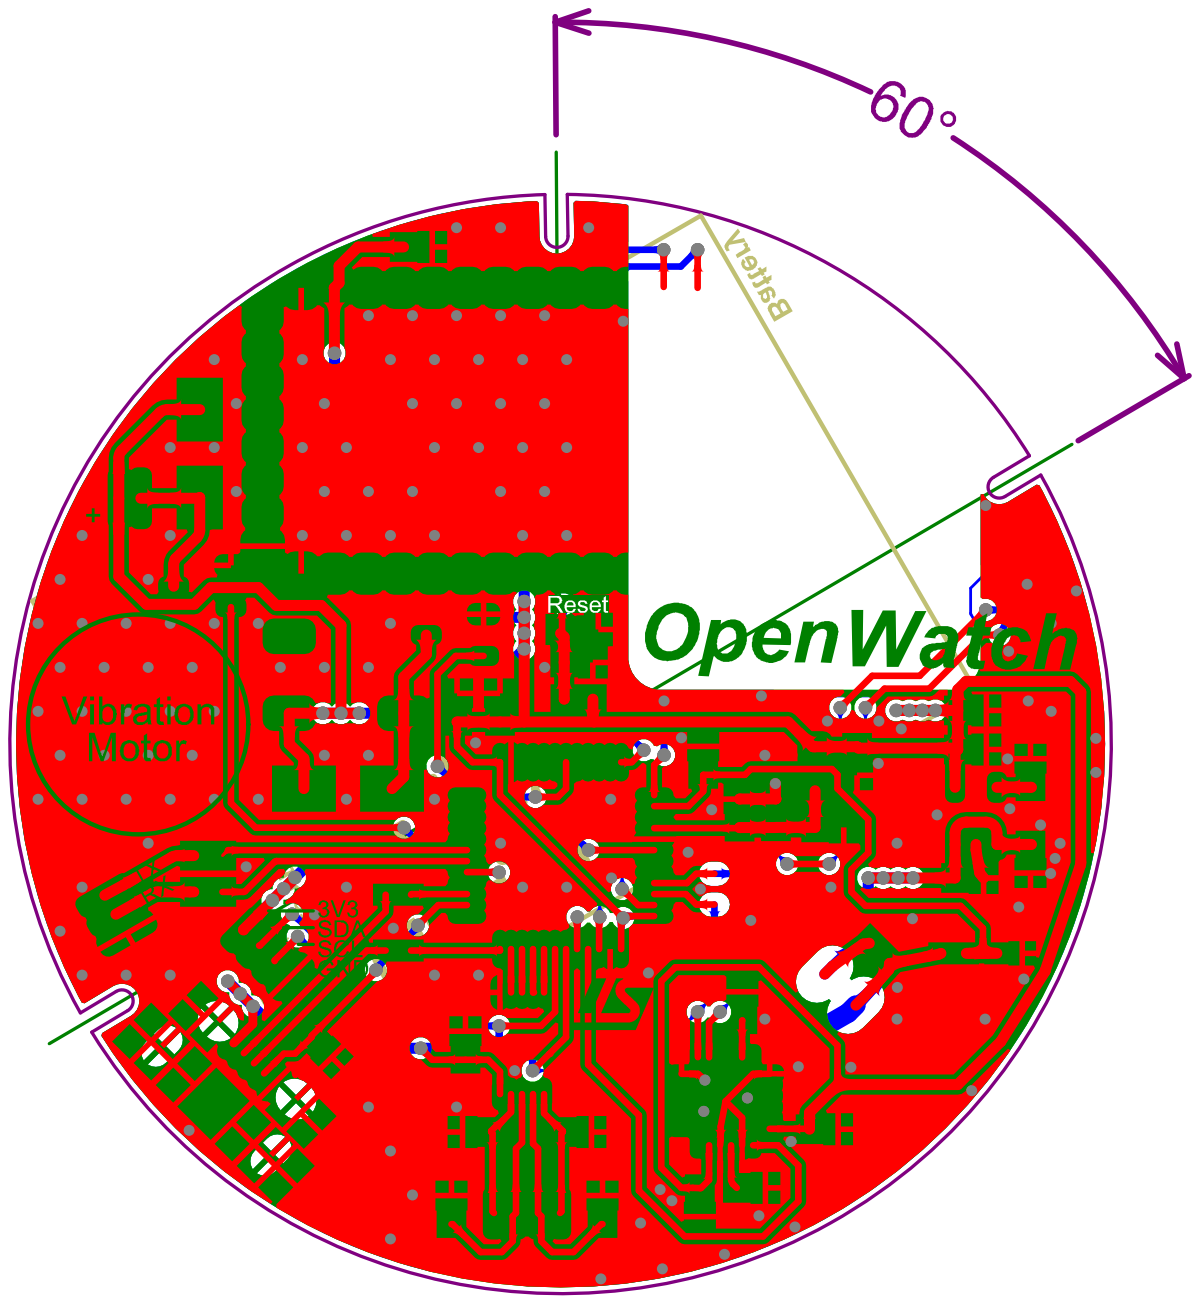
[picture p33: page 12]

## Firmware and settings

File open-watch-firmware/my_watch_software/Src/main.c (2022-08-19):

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
/* Includes ------------------------------------------------------------------*/
#include "main.h"
#include "adc.h"
#include "dma.h"
#include "i2c.h"
#include "rtc.h"
#include "tim.h"
#include "usart.h"
#include "gpio.h"

/* USER CODE BEGIN Includes */
#include "ey_iran.h"
#include "MPU6050.h"
#include "Kalman.h"
#include "max30102_for_stm32_hal.h"
#include "ssd1306.h"
#include "fonts.h"
#include "stdio.h"
#include "pages.h"
#include "xfer.h"
#include "system.h"
/* USER CODE END Includes */

/* USER CODE BEGIN PD */

#define MDELAY_TIMER_VALUE (TIM17->CNT)
#define MDELAY_TIMER		htim17		// No IT - each 0.001 seconds - used to create a timer-based delay function (MHAL_Delay)
#define SCREEN_TIMER_RESET (TIM16->CNT = 0)
#define SCREEN_TIMER		htim16		// IT mode - each 4 seconds
#define BATERY_TIMER		htim15		// IT mode - each 0.01 seconds
#define SYSTEM_TIMER		htim14		// IT mode - each 0.25 seconds
#define KALMAN_TIMER		htim6			// IT mode - each 0.001 seconds
#define BUZZER_TIMER		htim3			// PWM mode - 1KHz - Value from 0 to 999
#define VIBMOT_TIMER		htim1			// PWM mode - 1KHz - Value from 0 to 4999

/* USER CODE END PD */


/* USER CODE BEGIN PV */
System sys;

int display_fake_delay = 0;
int timeout_counter = 0;
int _index = 0; 

/* Batery Level */
uint32_t adcVals[128];
uint32_t sum = 0;

uint8_t TxBuffer[12];

/* PPG Sensor */
max30102_t max30102;
uint8_t en_reg[2] = {0};

/* Movement */
MPU_ConfigTypeDef myMpuConfig;
RawData_Def myAccelRaw, myGyroRaw;
KalmanScaler KAccel;
Kalman2D1R KGyro;

/* USER CODE END PV */

void SystemClock_Config(void);
/* USER CODE BEGIN PFP */

void HAL_TIM_PeriodElapsedCallback(TIM_HandleTypeDef *htim);
void HAL_GPIO_EXTI_Callback(uint16_t GPIO_Pin);
void HAL_UART_RxCpltCallback(UART_HandleTypeDef *huart);
void HAL_RTC_AlarmAEventCallback(RTC_HandleTypeDef *hrtc);
void HAL_ADC_ConvCpltCallback(ADC_HandleTypeDef* hadc);
void max30102_plot(uint32_t ir_sample, uint32_t red_sample);
void max30102_turn_on(void);
void max30102_turn_off(void);
void set_vib(int speed, int duration);
void set_tone(int freq, int duration);
void set_tone_vib(int freq, int duration);
void beeb_beeb(System* sys, int freq, int duration);
void MHAL_Delay(uint32_t Delay);

/* USER CODE END PFP */

/**
  * @brief  The application entry point.
  * @retval int
  */
int main(void)
{
  /* MCU Configuration--------------------------------------------------------*/

  /* Reset of all peripherals, Initializes the Flash interface and the Systick. */
  HAL_Init();

  /* Configure the system clock */
  SystemClock_Config();

  /* Initialize all configured peripherals */
  MX_GPIO_Init();
  MX_DMA_Init();
  MX_I2C1_Init();
  MX_RTC_Init();
  MX_TIM1_Init();
  MX_TIM3_Init();
  MX_USART1_UART_Init();
  MX_ADC_Init();
  MX_USART2_UART_Init();
  MX_TIM6_Init();
  MX_TIM15_Init();
  MX_TIM14_Init();
  MX_TIM16_Init();
  MX_TIM17_Init();
  /* USER CODE BEGIN 2 */
	
	/* // I2C scanner
		int ret = 0;		
		HAL_GPIO_WritePin(MAX_EN_GPIO_Port, MAX_EN_Pin, GPIO_PIN_SET);
		DEBUG("Starting I2C Scanning: \n\r ");
		for(int i=1; i<128; i++){
			ret = HAL_I2C_IsDeviceReady(&hi2c1, (uint16_t)(i<<1), 3, 5);
			if (ret != HAL_OK)
				DEBUG(" - ");
			else if(ret == HAL_OK)
				DEBUG("0x%X", i);
		}
		DEBUG("\n\rDone! \n\r ");
		HAL_GPIO_WritePin(MAX_EN_GPIO_Port, MAX_EN_Pin, GPIO_PIN_RESET);
	//*/
	
	/*/ // Date and Time setting
	DEBUG("Date and Time setting...  ");
		RTC_DateTypeDef DateToBeSet;
		DateToBeSet.Year = 22;
		DateToBeSet.Month = 8;
		DateToBeSet.Date = 4;
		DateToBeSet.WeekDay = RTC_WEEKDAY_THURSDAY;
		
		RTC_TimeTypeDef TimeToBeSet;
		TimeToBeSet.Hours = 17;
		TimeToBeSet.Minutes = 16;
		TimeToBeSet.Seconds = 30;
		
		HAL_RTC_SetDate(&hrtc, &DateToBeSet, RTC_FORMAT_BIN);
		HAL_RTC_SetTime(&hrtc, &TimeToBeSet, RTC_FORMAT_BIN);
	DEBUG("  Done! \n\r ");
	HAL_Delay(2000);
	//*/
	
	/*/ // Alarm setting
	DEBUG("Alarm setting...  ");
		RTC_AlarmTypeDef sAlarm = {0};
		sAlarm.AlarmTime.Hours = 17;
		sAlarm.AlarmTime.Minutes = 0;
		sAlarm.AlarmTime.Seconds = 0;
		sAlarm.AlarmTime.SubSeconds = 0;
		sAlarm.AlarmTime.DayLightSaving = RTC_DAYLIGHTSAVING_NONE;
		sAlarm.AlarmTime.StoreOperation = RTC_STOREOPERATION_RESET;
		sAlarm.AlarmMask = RTC_ALARMMASK_DATEWEEKDAY;
		sAlarm.AlarmSubSecondMask = RTC_ALARMSUBSECONDMASK_ALL;
		sAlarm.AlarmDateWeekDaySel = RTC_ALARMDATEWEEKDAYSEL_WEEKDAY;
		sAlarm.AlarmDateWeekDay = RTC_WEEKDAY_FRIDAY;
		sAlarm.Alarm = RTC_ALARM_A;
		HAL_RTC_SetAlarm_IT(&hrtc, &sAlarm, RTC_FORMAT_BIN);
	DEBUG("  Done! \n\r ");
	HAL_Delay(2000);
	//*/
	
	//* // Display initiation
	DEBUG("Display initiation...  ");
		ssd1306_Init(&hi2c1);
	DEBUG("  Done! \n\r ");
	HAL_Delay(2000);
	//*/
	
	//* // System initiation
	DEBUG("System initiation...  ");
		sys = sys_init();
		HAL_TIM_Base_Start_IT(&SYSTEM_TIMER);
	DEBUG("  Done! \n\r ");
	HAL_Delay(2000);
	//*/
		
	//* // MPU6050 initiation
	DEBUG("MPU6050 initiation...  ");
		MPU6050_Init(&hi2c1);
		myMpuConfig.Accel_Full_Scale = AFS_SEL_4g;
		myMpuConfig.ClockSource = Internal_8MHz;
		myMpuConfig.CONFIG_DLPF = DLPF_94A_98G_Hz;
		myMpuConfig.Gyro_Full_Scale = FS_SEL_2000;
		myMpuConfig.Sleep_Mode_Bit = 0;
		MPU6050_Config(&myMpuConfig); 
	DEBUG("  Done! \n\r ");
	HAL_Delay(2000);
	//*/
		 
	//* // Bluetooth initiation
	DEBUG("Bluetooth initiation...  ");
		HAL_UART_Receive_DMA(&BLUETOOTH_UART, sys.RxBuffer, RX_BUFFER_SIZE);
	
	/* // Bluetooth settings
		uint8_t psize = 0;
		char setting_buffer[25];
		psize = sprintf(setting_buffer, "AT+NAMEOpenWatch");
		HAL_UART_Transmit(&BLUETOOTH_UART, (uint8_t*)setting_buffer, psize, 1000);
		psize = sprintf(setting_buffer, "AT+PIN8569");
		HAL_UART_Transmit(&BLUETOOTH_UART, (uint8_t*)setting_buffer, psize, 1000);
		psize = sprintf(setting_buffer, "AT+BAUD8"); // 115200 bps
		HAL_UART_Transmit(&BLUETOOTH_UART, (uint8_t*)setting_buffer, psize, 1000);
		psize = sprintf(setting_buffer, "AT");
		HAL_UART_Transmit(&BLUETOOTH_UART, (uint8_t*)setting_buffer, psize, 1000);
		while(1);
	//*/
	
	DEBUG("  Done! \n\r ");
	HAL_Delay(2000);
	//*/
	
	//* // Baettery level ADC settings
	DEBUG("Baettery level ADC settings...  ");
		HAL_ADC_Start_DMA(&hadc, adcVals, 128);
		HAL_TIM_Base_Start(&BATERY_TIMER); 
	DEBUG("  Done! \n\r ");
	HAL_Delay(2000);
	//*/
	
	//* // Kalman filter initiation
	DEBUG("Kalman filter initiation...  ");
		kalman_scaler_init(&KAccel, 0.8, 900);
		kalman_2d1r_init(&KGyro, 0.1, 1);
		HAL_TIM_Base_Start_IT(&KALMAN_TIMER);	
	DEBUG("  Done! \n\r ");
	HAL_Delay(2000);
	//*/

  /* USER CODE END 2 */

  /* Infinite loop */
  /* USER CODE BEGIN WHILE */
  while (1)
	{
		
		// Ringing in case of activated alarms
		if(getRinging(&sys)){
			for(int thisNote=0; thisNote<sizeof(melody)/sizeof(int); thisNote++){
				beeb_beeb(&sys, melody[thisNote], 1200/noteDurations[thisNote]);
				if(!getRinging(&sys))
					break;
			}
		} 

    /* USER CODE END WHILE */

    /* USER CODE BEGIN 3 */
  } 
  /* USER CODE END 3 */
}

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
/* USER CODE BEGIN 4 */
 
void HAL_TIM_PeriodElapsedCallback(TIM_HandleTypeDef *htim){
	if(htim == &KALMAN_TIMER){
		MPU6050_Get_RawData(&myAccelRaw, &myGyroRaw);
		
		/*
		TxBuffer[0] = (uint8_t)(myAccelRaw.x & 0x00FF);
		TxBuffer[1] = (uint8_t)((myAccelRaw.x & 0xFF00)>>8);
		
		TxBuffer[2] = (uint8_t)(myAccelRaw.y & 0x00FF);
		TxBuffer[3] = (uint8_t)((myAccelRaw.y & 0xFF00)>>8);

		TxBuffer[4] = (uint8_t)(myAccelRaw.z & 0x00FF);
		TxBuffer[5] = (uint8_t)((myAccelRaw.z & 0xFF00)>>8);
		
		TxBuffer[6] = (uint8_t)(myGyroRaw.x & 0x00FF);
		TxBuffer[7] = (uint8_t)((myGyroRaw.x & 0xFF00)>>8);
		
		TxBuffer[8] = (uint8_t)(myGyroRaw.y & 0x00FF);
		TxBuffer[9] = (uint8_t)((myGyroRaw.y & 0xFF00)>>8);
		
		TxBuffer[10] = (uint8_t)(myGyroRaw.z & 0x00FF);
		TxBuffer[11] = (uint8_t)((myGyroRaw.z & 0xFF00)>>8);
		//*/
		
		// Filtering ---------------------------------------
		
		/* Accelerometer */
		KAccel.z_x = myAccelRaw.x;
		#if ALLXYZ_MODE
			KAccel.z_y = myAccelRaw.y;
			KAccel.z_z = myAccelRaw.z;
		#endif
		kalman_scaler_update(&KAccel); 
		
		/* Gyroscope */
		#if ALLXYZ_MODE
			KGyro.z_x = myGyroRaw.x;
			KGyro.z_z = myGyroRaw.z;
		#endif
		KGyro.z_y = myGyroRaw.y;
		kalman_2d1r_update(&KGyro); 

		/* Pedometer */
		if((KAccel.x_hat >= 3200)&&(!getPedFlag(&sys))){
			setPedFlag(&sys,1);
			sys.pedometer += 2;
			//DEBUG("%d\n\r",sys.pedometer);
		}
		else if((KAccel.x_hat < 2500)&&(getPedFlag(&sys))){ 
			setPedFlag(&sys,0);
		}
		
		/* Enable screen */
		if((KGyro.wy_hat >= 4000)&&(!getScreenFlag(&sys))){
			setScreenFlag(&sys,1);
		}
		else if((KAccel.x_hat < 400)&&(getScreenFlag(&sys))){
			setScreenFlag(&sys,0);
			HAL_TIM_Base_Start_IT(&SCREEN_TIMER);
			setScreenEable(&sys,1);
		}
		
		// Filtererd data ----------------------------------
		/*
		TxBuffer[12-12] = (uint8_t)(KAccel.x_hat & 0x00FF);
		TxBuffer[13-12] = (uint8_t)((KAccel.x_hat & 0xFF00)>>8);
		
		TxBuffer[14-12] = (uint8_t)(KAccel.y_hat & 0x00FF);
		TxBuffer[15-12] = (uint8_t)((KAccel.y_hat & 0xFF00)>>8);

		TxBuffer[16-12] = (uint8_t)(KAccel.z_hat & 0x00FF);
		TxBuffer[17-12] = (uint8_t)((KAccel.z_hat & 0xFF00)>>8);
		
		TxBuffer[18-12] = (uint8_t)(KGyro.wx_hat & 0x00FF);
		TxBuffer[19-12] = (uint8_t)((KGyro.wx_hat & 0xFF00)>>8);
		
		TxBuffer[20-12] = (uint8_t)(KGyro.wy_hat & 0x00FF);
		TxBuffer[21-12] = (uint8_t)((KGyro.wy_hat & 0xFF00)>>8);
		
		TxBuffer[22-12] = (uint8_t)(KGyro.wz_hat & 0x00FF);
		TxBuffer[23-12] = (uint8_t)((KGyro.wz_hat & 0xFF00)>>8);
		//*/
		
		//HAL_UART_Transmit(&BLUETOOTH_UART, (uint8_t*)TxBuffer, 12, 10);
	}
	else if(htim == &SYSTEM_TIMER){
		if(getScreenEable(&sys)){
			sys.battery = map(sys.voltage, 3000, 3907, 0, 100);
			switch (sys.state)
			{
				case ack_waiting:
						HAL_TIM_Base_Stop(&SCREEN_TIMER);
						render_ack_waiting(&sys);
					break;
				case hello:
						if(display_fake_delay<16){
							render_connected(&sys);
							display_fake_delay++;
						}
						else{
							sys.state = home;
							display_fake_delay = 0;
							SCREEN_TIMER_RESET;
							HAL_TIM_Base_Start_IT(&SCREEN_TIMER);
						}
					break;
				case home:
						HAL_RTC_GetTime(&hrtc, &sys.Time, RTC_FORMAT_BIN);
						HAL_RTC_GetDate(&hrtc, &sys.Date, RTC_FORMAT_BIN);
						render_home(&sys);
					break;
				case bloody_hell:
						HAL_TIM_Base_Stop(&SCREEN_TIMER);
						render_bloody_hell(&sys);
					break;
				case pedomedo:
						HAL_TIM_Base_Stop(&SCREEN_TIMER);
						render_pedomedo(&sys);
					break;
				case about:
						HAL_TIM_Base_Stop(&SCREEN_TIMER);
						render_about(&sys);
					break;
				case ringing:
						HAL_TIM_Base_Stop(&SCREEN_TIMER);
						render_ringing(&sys);
					break;
			}
			if(sys.state != bloody_hell){
				if(timeout_counter < 4){
					timeout_counter++;
				}
				else{
					setConnected(&sys, getSHRreached(&sys));
					sys.ack = getConnected(&sys);
					setSHRreached(&sys, 0);
					timeout_counter = 0;
				}
			}
		}
		else{
			ssd1306_Fill(Black);
			ssd1306_UpdateScreen(&hi2c1);
		}
	}
	else if(htim == &SCREEN_TIMER){
		HAL_TIM_Base_Stop(&SCREEN_TIMER);
		setScreenEable(&sys, 0);
		SCREEN_TIMER_RESET;
	}
}

void HAL_GPIO_EXTI_Callback(uint16_t GPIO_Pin){
	if (GPIO_Pin == MAX_INT_Pin) {
		max30102_interrupt_handler(&max30102);
	}
	else if(GPIO_Pin == KEY4_Pin){
		DEBUG("UP PRESSED \n\r");
		if(!getScreenEable(&sys)){
			//
		}
		else{
			SCREEN_TIMER_RESET;
			switch (sys.state)
			{
				case ack_waiting:
						// accept
						sys.ack = 1;
						TxGenerator(&sys);
					break;
				case hello:
						//
					break;
				case home:
						sys.state = about;
					break;
				case bloody_hell:
						max30102_turn_off();
						HAL_TIM_Base_Start_IT(&BATERY_TIMER);
						HAL_TIM_Base_Start_IT(&KALMAN_TIMER);
				
						sys.state = home;
						SCREEN_TIMER_RESET;
						HAL_TIM_Base_Start_IT(&SCREEN_TIMER);
					break;
				case pedomedo:
						HAL_TIM_Base_Stop(&KALMAN_TIMER);
						HAL_TIM_Base_Stop(&BATERY_TIMER);
						max30102_turn_on();
						sys.state = bloody_hell;
					break;
				case about:
						sys.state = pedomedo;
					break;
				case ringing:
						SCREEN_TIMER_RESET;
						setRinging(&sys, 0);
						HAL_TIM_Base_Start_IT(&KALMAN_TIMER);
						HAL_TIM_Base_Start_IT(&SCREEN_TIMER);
						sys.state = home;
					break;
			}
			beeb_beeb(&sys, 500, 100);
		}
	}
	else if(GPIO_Pin == KEY3_Pin){
		DEBUG("RIGHT PRESSED \n\r");
		if(!getScreenEable(&sys)){
			//
		}
		else{
			SCREEN_TIMER_RESET;
			switch (sys.state)
			{
				case ack_waiting:
						sys.state = ringing;
					break;
				case hello:
						//
					break;
				case home:
						sys.state = ack_waiting;
					break;
				case bloody_hell:
						//
					break;
				case pedomedo:
						//
					break;
				case about:
						//
					break;
				case ringing:
						SCREEN_TIMER_RESET;
						setRinging(&sys, 0);
						HAL_TIM_Base_Start_IT(&KALMAN_TIMER);
						HAL_TIM_Base_Start_IT(&SCREEN_TIMER);
						sys.state = home; 
					break;
			}
			beeb_beeb(&sys, 500, 100);
		}
	}
	else if(GPIO_Pin == KEY2_Pin){
		DEBUG("DOWN PRESSED \n\r");
		if(!getScreenEable(&sys)){
			sys.state = home;
			HAL_TIM_Base_Start_IT(&SCREEN_TIMER);
			setScreenEable(&sys,1);
		}
		else{
			SCREEN_TIMER_RESET;
			switch (sys.state)
			{
				case ack_waiting:
						// reject
						sys.ack = 0;
						TxGenerator(&sys);
						sys.state = home;
						setScreenEable(&sys,0);
					break;
				case hello:
						//
					break;
				case home:
						HAL_TIM_Base_Stop(&KALMAN_TIMER);
						HAL_TIM_Base_Stop(&BATERY_TIMER);
						max30102_turn_on();
						sys.state = bloody_hell;
					break;
				case bloody_hell:
						max30102_turn_off();
						HAL_TIM_Base_Start_IT(&BATERY_TIMER);
						HAL_TIM_Base_Start_IT(&KALMAN_TIMER);
						sys.state = pedomedo;
					break;
				case pedomedo:
						sys.state = about;
					break;
				case about:
						SCREEN_TIMER_RESET;
						HAL_TIM_Base_Start_IT(&SCREEN_TIMER);
						sys.state = home;
					break;
				case ringing:
						SCREEN_TIMER_RESET;
						setRinging(&sys, 0);
						HAL_TIM_Base_Start_IT(&KALMAN_TIMER);
						HAL_TIM_Base_Start_IT(&SCREEN_TIMER);
						sys.state = home;
					break;
			}
			beeb_beeb(&sys, 500, 100);
		}
	}
	else if(GPIO_Pin == KEY1_Pin){
		DEBUG("LEFT PRESSED \n\r");
		if(!getScreenEable(&sys)){
			//
		}
		else{
			SCREEN_TIMER_RESET;
			switch (sys.state)
			{
				case ack_waiting:
						SCREEN_TIMER_RESET;
						setRinging(&sys, 0);
						HAL_TIM_Base_Start_IT(&KALMAN_TIMER);
						HAL_TIM_Base_Start_IT(&SCREEN_TIMER);
						sys.state = home;
					break;
				case hello:
						//
					break;
				case home:
						sys.state = ringing;
					break;
				case bloody_hell:
						//
					break;
				case pedomedo:
						//
					break;
				case about:
						//
					break;
				case ringing:
						sys.state = ack_waiting;
					break;
			}
			beeb_beeb(&sys, 500, 100);
		}
	}
}

void HAL_UART_RxCpltCallback(UART_HandleTypeDef *huart){
	if(huart==&BLUETOOTH_UART){
		RxParser(&sys);
	}
}

void HAL_RTC_AlarmAEventCallback(RTC_HandleTypeDef *hrtc){
	if(sys.isAlarmEnabled){
		sys.state = ringing;
		HAL_TIM_Base_Stop(&KALMAN_TIMER);
		setRinging(&sys, 1);
		setScreenEable(&sys,1);
	}
}

void HAL_ADC_ConvCpltCallback(ADC_HandleTypeDef* hadc){
	sum = 0;
	for(uint32_t i = 0; i<128; i++)
		sum += adcVals[i];
	sys.voltage = sum >> 7;
	
}
void max30102_plot(uint32_t ir_sample, uint32_t red_sample){
	append_PPG_buffer(&sys, ir_sample, red_sample);
}
void max30102_turn_on(void){
	clear_PPG_buffer(&sys);
	
	HAL_GPIO_WritePin(MAX_EN_GPIO_Port, MAX_EN_Pin, GPIO_PIN_SET);
	
	// Initiation
	max30102_init(&max30102, &hi2c1);
	max30102_reset(&max30102);
	max30102_clear_fifo(&max30102);
	max30102_set_fifo_config(&max30102, max30102_smp_ave_8, 1, 7);
	
	// Sensor settings
	max30102_set_led_pulse_width(&max30102, max30102_pw_16_bit);
	max30102_set_adc_resolution(&max30102, max30102_adc_2048);
	max30102_set_sampling_rate(&max30102, max30102_sr_1000);
	max30102_set_led_current_1(&max30102, 6.2);
	max30102_set_led_current_2(&max30102, 6.2);

	// Enter SpO2 mode
	max30102_set_mode(&max30102, max30102_spo2);
	max30102_set_a_full(&max30102, 1);
	
	// Initiate 1 temperature measurement
	max30102_set_die_temp_en(&max30102, 1);
	max30102_set_die_temp_rdy(&max30102, 1);

	max30102_read(&max30102, 0x00, en_reg, 1);
}
void max30102_turn_off(void){
	HAL_GPIO_WritePin(MAX_EN_GPIO_Port, MAX_EN_Pin, GPIO_PIN_RESET);
}
void set_vib(int freq, int duration){
	HAL_TIM_PWM_Start(&VIBMOT_TIMER, TIM_CHANNEL_4);
	__HAL_TIM_SET_AUTORELOAD(&VIBMOT_TIMER, 5000);
	__HAL_TIM_SET_COMPARE(&VIBMOT_TIMER, TIM_CHANNEL_4, (int)map(freq, 260, 500, 2000, 5000));
	MHAL_Delay(duration);
	HAL_TIM_PWM_Stop(&VIBMOT_TIMER, TIM_CHANNEL_4);
	MHAL_Delay((int)(duration*0.3));
}

void set_tone(int freq, int duration){
	HAL_TIM_PWM_Start(&BUZZER_TIMER, TIM_CHANNEL_3);
	__HAL_TIM_SET_AUTORELOAD(&BUZZER_TIMER, 1000000/freq);
	__HAL_TIM_SET_COMPARE(&BUZZER_TIMER, TIM_CHANNEL_3, 1000000/freq/2);
	MHAL_Delay(duration);
	HAL_TIM_PWM_Stop(&BUZZER_TIMER, TIM_CHANNEL_3);
	MHAL_Delay((int)(duration*0.3));
}

void set_tone_vib(int freq, int duration){
	HAL_TIM_PWM_Start(&VIBMOT_TIMER, TIM_CHANNEL_4);
	__HAL_TIM_SET_AUTORELOAD(&VIBMOT_TIMER, 5000);
	__HAL_TIM_SET_COMPARE(&VIBMOT_TIMER, TIM_CHANNEL_4, (int)map(freq, 260, 500, 2000, 5000));
	HAL_TIM_PWM_Start(&BUZZER_TIMER, TIM_CHANNEL_3);
	__HAL_TIM_SET_AUTORELOAD(&BUZZER_TIMER, 1000000/freq);
	__HAL_TIM_SET_COMPARE(&BUZZER_TIMER, TIM_CHANNEL_3, 1000000/freq/2);
	MHAL_Delay(duration);
	HAL_TIM_PWM_Stop(&BUZZER_TIMER, TIM_CHANNEL_3);
	HAL_TIM_PWM_Stop(&VIBMOT_TIMER, TIM_CHANNEL_4);
	MHAL_Delay((int)(duration*0.3));
}

void beeb_beeb(System* sys, int freq, int duration){
	if(getSoundEnable(sys) && getVibEnable(sys))
		set_tone_vib(freq, duration);
	else if(getSoundEnable(sys) && (!getVibEnable(sys)))
		set_tone(freq, duration);
	else if((!getSoundEnable(sys)) && getVibEnable(sys))
		set_vib(freq, duration);
}

void MHAL_Delay(uint32_t Delay){
	HAL_TIM_Base_Start(&MDELAY_TIMER);
	while(MDELAY_TIMER_VALUE < Delay);
	HAL_TIM_Base_Stop(&MDELAY_TIMER);
	MDELAY_TIMER_VALUE = 0;
}
/* USER CODE END 4 */
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


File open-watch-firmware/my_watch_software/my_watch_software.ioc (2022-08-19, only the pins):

Mcu.UserName=STM32F030C8Tx
PA1.Signal=ADC_IN1
PA10.Signal=USART1_RX
PA11.Signal=S_TIM1_CH4
PA13.Signal=SYS_SWDIO
PA14.Signal=SYS_SWCLK
PA15.GPIO_Label=KEY1
PA15.Signal=GPXTI15
PA2.Signal=USART2_TX
PA3.Signal=USART2_RX
PA9.Signal=USART1_TX
PB0.Signal=S_TIM3_CH3
PB3.GPIO_Label=KEY2
PB3.Signal=GPXTI3
PB4.GPIO_Label=KEY3
PB4.Signal=GPXTI4
PB5.GPIO_Label=KEY4
PB5.Signal=GPXTI5
PB6.Signal=I2C1_SCL
PB7.Signal=I2C1_SDA
PB8.GPIO_Label=MPU_INT
PB8.Signal=GPXTI8
PB9.GPIO_Label=MAX_INT
PB9.Signal=GPXTI9
PC13.GPIO_Label=MAX_EN
PC13.Signal=GPIO_Output
PC14-OSC32_IN.Signal=RCC_OSC32_IN
PC15-OSC32_OUT.Signal=RCC_OSC32_OUT
PF6.GPIO_Label=USB_DET
PF6.Signal=GPXTI6

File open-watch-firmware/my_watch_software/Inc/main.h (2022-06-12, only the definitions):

#define SAMPLING_TIME ((htim6.Init.Period+1)/((float)1e6)); /*** KALMAN_TIMER ***/
#define MAX_EN_Pin GPIO_PIN_13
#define MAX_EN_GPIO_Port GPIOC
#define USB_DET_Pin GPIO_PIN_6
#define USB_DET_GPIO_Port GPIOF
#define USB_DET_EXTI_IRQn EXTI4_15_IRQn
#define KEY1_Pin GPIO_PIN_15
#define KEY1_GPIO_Port GPIOA
#define KEY1_EXTI_IRQn EXTI4_15_IRQn
#define KEY2_Pin GPIO_PIN_3
#define KEY2_GPIO_Port GPIOB
#define KEY2_EXTI_IRQn EXTI2_3_IRQn
#define KEY3_Pin GPIO_PIN_4
#define KEY3_GPIO_Port GPIOB
#define KEY3_EXTI_IRQn EXTI4_15_IRQn
#define KEY4_Pin GPIO_PIN_5
#define KEY4_GPIO_Port GPIOB
#define KEY4_EXTI_IRQn EXTI4_15_IRQn
#define MPU_INT_Pin GPIO_PIN_8
#define MPU_INT_GPIO_Port GPIOB
#define MPU_INT_EXTI_IRQn EXTI4_15_IRQn
#define MAX_INT_Pin GPIO_PIN_9
#define MAX_INT_GPIO_Port GPIOB
#define MAX_INT_EXTI_IRQn EXTI4_15_IRQn

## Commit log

2020-11-02 Body size changed, Schematic design improved
    [Bluetooth.SchDoc, GyroMPU.SchDoc, MCU.SchDoc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]
2020-11-06 Battery size & connector changed
    [MCU.SchDoc, OLED.SchDoc, watch_pcb.PcbDoc]
2020-11-08 added touch buttons
    [MCU.SchDoc, OLED.SchDoc, Touch.SchDoc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]
2020-11-08 new PCB with touch
2020-11-09 Buzzer added
    [Buzzer.SchDoc, MCU.SchDoc, Touch.SchDoc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]
2020-11-09 added 3.3V regulator
2020-11-13 Tempereture sensor added + Programming port changed
    [Buzzer.SchDoc, MCU.SchDoc, main.SchDoc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]
2020-11-16 Tempereture sensor pin changed
2020-11-16 On-board battery charger added
    [Charger.SchDoc, MCU.SchDoc, Viberation.SchDoc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]
2020-12-24 added real PCB pictures
2021-02-25 Version 1.0
    [Charger.SchDoc, GyroMPU.SchDoc]
2021-11-09 Final version of PCB added
    [Bluetooth.SchDoc, Buzzer.SchDoc, Charger.SchDoc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]
2021-11-21 Real PCB picures added
2021-12-18 soldered pcb picture added
2022-01-09 MPU6050 + MAX30102 + Bluetooth + RTC + Battery level + Music player + Vibration handler added to the codes
    [MPU6050.c, main.c]
2022-05-23 body V3.0 added
    [back.SLDPRT, main.SLDPRT]
2022-06-12 Kalman filter added (Gyro Y has problem)
    [main.c]
2022-06-12 Kalman filter completed
2022-06-15 Fast Kalman filter added + pedometer added + gyroscope screen trigger added
2022-06-16 Mechanical parts updated (PCBWay 3D printing version)
    [back.SLDPRT, back.STL, main.SLDPRT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]
2022-06-17 ADC and PWM timers were seperated + some cleanings
2022-06-25 System struct and function prototypes added + Bluetooth uart baudrate changed to 115200

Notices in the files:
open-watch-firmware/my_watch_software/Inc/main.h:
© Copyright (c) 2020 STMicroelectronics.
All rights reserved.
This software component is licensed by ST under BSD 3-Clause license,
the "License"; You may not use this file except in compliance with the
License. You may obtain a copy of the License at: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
